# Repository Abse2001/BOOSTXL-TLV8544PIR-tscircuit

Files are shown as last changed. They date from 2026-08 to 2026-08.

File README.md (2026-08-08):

# BOOSTXL-TLV8544PIR tscircuit reconstruction

This is an engineering reconstruction of Texas Instruments' `BOOSTXL-TLV8544PIR` PIR motion-detector BoosterPack.

## Current status

- The complete 70-component, 40-net design is written directly in `index.circuit.tsx`. There is no secondary board file and no project-local component wrapper layer.
- Resistors and capacitors use native tscircuit elements. Every other populated electronic part is instantiated from an exact JLCPCB import: J1-J4, U1-U3, A1, D1-D5, L1/L2, and TP1/TP2.
- TI's two-page schematic was transcribed from SNOU148A Figures 27 and 28 and laid out as two native tscircuit sheets with five native schematic sections. Compact named traces keep every net label at eight characters or fewer and clear of the section dividers. U1 is projected as U1A-U1D op-amp units, the LaunchPad connectors/LEDs sit below the PIR signal chain, and the power/current-monitor circuit occupies sheet 2. C22 is correctly placed across R21, and NT1/NT2/NT3 preserve TI's rail split.
- The unpublished original U3 identity is not guessed. `TLV333IDBVR` is explicitly selected as a qualified, orderable unity-gain-buffer substitute and uses its exact JLCPCB C473369 import with corrected data-sheet pin labels.
- The obsolete SMT PIR is replaced by Murata `IRA-S210ST01` (JLCPCB C152563), using its exact imported three-lead through-hole footprint. The matching lens is Murata `IML-0688`.
- Every populated electrical component has a manufacturer part number and a JLCPCB/LCSC part number. J3/J4 use imported DEALON DZ254S-11-02-48 C5160785 vertical SMT headers, and TP1/TP2 use imported Keystone 5001 C238122.
- The reconstructed board is 60.96 mm × 50.8 mm. Its 43.18-mm header-center spacing (45.72 mm between outer header columns), asymmetric overhang, three holes, and outline are inferred from TI's scale image and BoosterPack grid because TI did not publish native PCB CAD for this board.
- The local v6 router completes 131 PCB traces with 117 vias, 0.30-mm via drills, 0.45-mm via pads, and a bottom GND pour. The circuit JSON contains zero placement, routing, or connectivity errors.
- `bun run release-check` enforces 70 physical components plus the five schematic-only U1/U3 projections, compact schematic labels and divider clearance, net count, routing, zero circuit errors, critical MPNs, supplier coverage, the corrected C22/NT/U3/A1 topology, and a Gerber-mode `tsci check shorts` pass.

## Release status

This is an **orderable prototype release candidate**, not a production-proven clone. The electrical values, topology, MPNs, footprints, and supplier IDs are now traceable. Before paying for assembly, print the 1:1 mechanical overlay and confirm the reconstructed outline/header/hole/lens geometry against the intended LaunchPad. After assembly, execute `docs/bring-up-plan.md`; the IRA-S210 substitution and lens housing require first-article qualification.

- Public source and manufacturing package: <https://github.com/Abse2001/BOOSTXL-TLV8544PIR-tscircuit>
- Published tscircuit package: <https://tscircuit.com/abse/boostxl-tlv8544pir> (`1.0.13`)

The registry build uses the exact OBJ models for J1/J2 and U1 because its per-file upload limit rejects their larger STEP files. The complete STEP models remain in this repository and in the manufacturing exports; electrical and PCB geometry are unchanged.

See:

- `docs/design-verification.md` for value provenance and calculated checkpoints;
- `docs/manufacturing-status.md` for the remaining release gates;
- `docs/mechanical-integration.md` for the board/sensor/lens fit evidence;
- `manufacturing/procurement-status.csv` for exact purchasing selections; and
- `exports/README.md` for generated deliverables.

## Commands

```sh
bun install
bun run release-check
bun run dev
bunx tsci export index.circuit.tsx -f kicad_zip -o exports/BOOSTXL-TLV8544PIR-routed-kicad.zip --disable-parts-engine
```

The build output is written under `dist/`.

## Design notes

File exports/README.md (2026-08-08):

# Generated exports

All files in this directory were regenerated from the same circuit state that passes `bun run release-check`.

| File | Contents |
| --- | --- |
| `BOOSTXL-TLV8544PIR-schematic.svg` | Both TI-style schematic sheets in one stacked review drawing. |
| `BOOSTXL-TLV8544PIR-schematic-page-1.svg` | PIR signal conditioning, LaunchPad connectors, and user LEDs. |
| `BOOSTXL-TLV8544PIR-schematic-page-2.svg` | 3.3-V/5-V filtering, rail splits, current monitor, and U3 buffer. |
| `BOOSTXL-TLV8544PIR-routed-pcb.svg` | Courtyard-visible two-layer routed PCB preview. |
| `BOOSTXL-TLV8544PIR-assembly.svg` | Top assembly drawing with the exact three-lead A1 package. |
| `BOOSTXL-TLV8544PIR-readable-netlist.txt` | Human-readable 70-component/40-net report including selected MPNs. |
| `BOOSTXL-TLV8544PIR-circuit.json` | Complete release-check input/output: 131 PCB traces, 117 vias with 0.30-mm drills and 0.45-mm pads, zero error elements. |
| `BOOSTXL-TLV8544PIR-routed-kicad.zip` | KiCad schematic/PCB/project plus imported models for every non-resistor/non-capacitor electronic component, including J3/J4 and TP1/TP2. |
| `BOOSTXL-TLV8544PIR-gerbers.zip` | Gerber/drill manufacturing data for independent DFM review. |
| `BOOSTXL-TLV8544PIR.step` | Partial board-level STEP model. The standalone merger cannot parse several exact supplier STEP dialects, so use the KiCad ZIP for the separately bundled models. |
| `SHA256SUMS` | SHA-256 checksums for the generated deliverables. |

## Release warning

These files form an orderable **prototype release candidate**, not production-proven hardware. Complete the 1:1 overlay in `docs/mechanical-integration.md`, an independent fabricator-rule DRC/Gerber review, and the first-article tests in `docs/bring-up-plan.md` before a production quantity.

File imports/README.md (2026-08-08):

# JLCPCB / EasyEDA imports

All populated electronic parts other than resistors and capacitors are instantiated directly from components generated with `tsci import --jlcpcb --download --use-exact-footprint`. The exact supplier geometry and downloaded 3D models are retained.

| Designator(s) | Manufacturer part number | JLCPCB/LCSC ID |
| --- | --- | --- |
| U1 | TLV8544PWR | C2867322 |
| U2 | INA226AIDGSR | C49851 |
| U3 | TLV333IDBVR | C473369 |
| D1 | 19-217/R6C-AL1M2VY/3T | C72044 |
| D2 | 19-213/Y2C-CQ2R2L/3T(CY) | C72038 |
| D3 | 19-217/G7C-AN1P2/6T | C2986030 |
| D4, D5 | 1N4148X-TP | C507292 |
| L1, L2 | BLM18HE152SN1D | C82155 |
| J1, J2 | SSQ-110-03-G-D | C3323139 |
| J3, J4 | DZ254S-11-02-48 | C5160785 |
| A1 | IRA-S210ST01 | C152563 |
| TP1, TP2 | Keystone 5001 | C238122 |

The importer sanitized punctuation in several generated TypeScript identifiers and MPN strings. Component identifiers remain valid TypeScript, while the `manufacturerPartNumber` metadata was restored to the supplier's real MPN. The TLV333 import's generated pin aliases were also corrected against the data sheet: pin 2 is `V_NEG` and pin 4 is `IN_NEG`.

H1 is the Murata `IML-0688` Fresnel lens. It is mechanical rather than an electrical source component; its 10.8-mm envelope is shown on board silkscreen and its housing requirements are documented separately.

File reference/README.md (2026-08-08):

# TI reference-data inventory

Collected on 2026-08-07 from official Texas Instruments pages.

## Exact BOOSTXL-TLV8544PIR sources

| Local file | TI document | Contents |
| --- | --- | --- |
| `boostxl-tlv8544pir/BOOSTXL-TLV8544PIR-user-guide-SNOU148A.pdf` | [SNOU148A](https://www.ti.com/lit/pdf/snou148a) | Exact board guide; Figures 27 and 28 are the complete published two-page schematic. |
| `boostxl-tlv8544pir/ultra-low-power-PIR-design-SNAA301.pdf` | [SNAA301](https://www.ti.com/lit/pdf/snaa301) | Application note explaining the low-power PIR analog front end. |
| `rendered-schematics/boostxl-tlv8544pir-schematic-22.png` | SNOU148A page 22 | Verified rendering of schematic page 1. |
| `rendered-schematics/boostxl-tlv8544pir-schematic-23.png` | SNOU148A page 23 | Verified rendering of schematic page 2. |
| `rendered-board/boostxl-tlv8544pir-top-view-04.png` | SNOU148A page 4 | Verified annotated top-view rendering for placement and footprint research. |
| `boostxl-tlv8544pir/component-inventory.csv` | Transcribed from Figures 27-28 | Initial designator/value inventory for reconstruction. |
| `datasheets/TLV8544-datasheet.pdf` | [TLV8544](https://www.ti.com/lit/ds/symlink/tlv8544.pdf) | Quad nanopower op-amp datasheet. |
| `datasheets/INA226-datasheet.pdf` | [INA226](https://www.ti.com/lit/ds/symlink/ina226.pdf) | I2C current/power monitor datasheet. |
| `boosterpack-standard/launchpad-boosterpack-design-guide-SLAA542.pdf` | [SLAA542](https://www.ti.com/lit/pdf/slaa542) | LaunchPad/BoosterPack mechanical and electrical design guidance. |
| `datasheets/IRA-S210ST01-datasheet.pdf` | [Murata IRA-S210ST01](https://www.murata.com/en-global/products/sensor/infrared/products-search/selectionguide) | Selected supported lead-type PIR sensor package and pin data. |
| `datasheets/IML-0688-datasheet.pdf` | [Murata IML-0688](https://www.murata.com/~/media/webrenewal/products/sensor/infrared/lens/iml_spec_0688_en.pdf) | Matching Fresnel-lens dimensions and retention requirements. |

## Additional component evidence

- [Molex 87898-0204 product page](https://www.molex.com/en-us/products/part-detail/0878980204) and [SD-87898-001 drawing](https://www.molex.com/content/dam/molex/molex-dot-com/products/automated/en-us/salesdrawingpdf/878/87898/878980654_sd.pdf): exact J3/J4 series, two circuits, 2.54-mm pitch, and the recommended 1.27 mm × 2.96 mm SMT lands.
- [JLCPCB C3331260](https://jlcpcb.com/partdetail/MOLEX-0878980204/C3331260): exact TI J3/J4 Molex part, listed for pre-order but absent from the current tscircuit/EasyEDA importer.
- [JLCPCB C5160785](https://jlcpcb.com/partdetail/DEALON-DZ254S_11_0248/C5160785): selected stocked J3/J4 replacement; 1×2, 2.54-mm vertical SMT header with 6-mm upright pins.
- [JLCPCB C238122](https://jlcpcb.com/partdetail/Keystone-5001/C238122): exact Keystone 5001 through-hole test point used for TP1/TP2.
- TI's TIDA-01398 BOM identifies the obsolete SMT A1 as `IRS-B210ST01-R1`. A TI engineering response says `IRA-S210ST01` performance should be similar or equal and identifies package as the difference. This supports the project's explicit substitute; it is not treated as an exact BOOSTXL BOM.
- [TI TLV333 data sheet](https://www.ti.com/lit/ds/symlink/tlv333.pdf): operating limits and pinout for the explicit U3 substitute.

TI's current product page does **not** publish native KiCad, Altium, Gerber, pick-and-place, or BOM files for the exact `BOOSTXL-TLV8544PIR`. A public web and GitHub search also found no trustworthy community-native CAD mirror for this exact board. The published electrical source is the schematic embedded in SNOU148A. The exact PCB layout will therefore need to be reconstructed from the schematic, board photographs, and BoosterPack header standard.

## Related TIDA-01398 files

`TIDA-01398` uses the same TLV8544-based low-power PIR concept but is a different wireless reference-design PCB. Do not use its layout, BOM, or CAD files as though they were the BoosterPack.

The directory `tida-01398/` contains TI's public design guide, schematic, BOM, assembly drawing, PCB layer plots, and the original Altium project. The archive was also extracted to `tida-01398/altium-source/`; it contains `.PrjPcb`, `.SchDoc`, and `.PcbDoc` files that recent KiCad versions may import as an Altium project.

## TI downloads requiring login/export approval

These have not been copied into the project because TI gates them behind myTI/export approval:

- [SPRCAG5 - BOOSTXL-TLV8544PIR firmware](https://www.ti.com/tool/download/SPRCAG5)
- [SNOC036 - BOOSTXL-TLV8544PIR Windows GUI](https://www.ti.com/tool/download/SNOC036)
- [TIDCD86 - TIDA-01398 Gerbers](https://www.ti.com/lit/zip/tidcd86)
- [TIDCD87 - TIDA-01398 firmware](https://www.ti.com/tool/download/TIDCD87)

## Original-source gaps and project disposition

- The PIR sensor part number is not printed on the published BoosterPack schematic. The project records the evidence for the obsolete `IRS-B210ST01-R1` and deliberately substitutes exact-import `IRA-S210ST01` plus its matching `IML-0688` lens.
- `U3` is shown electrically but its MPN is not printed. The project deliberately selects and qualifies `TLV333IDBVR`; it does not claim this was TI's original device.
- TI does not publish brands for the passives/LEDs. The project freezes deliberate production selections meeting the printed values and ratings in `manufacturing/procurement-status.csv`.
- SLAA542 defines the connector grid but not this board's expanded outline, three hole positions, chamfers, or lens retention. Those image-derived details still require a 1:1 physical overlay.

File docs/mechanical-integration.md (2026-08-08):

# Mechanical integration

## Reconstructed board datum

The source uses millimetres with the board centered at `(0, 0)`:

- outline: 60.96 mm × 50.8 mm with 2.54-mm corner chamfers;
- J1 center: `(-17.78, 5.08)`;
- J2 center: `(25.40, 5.08)`;
- header-center separation: 43.18 mm; the two-row headers therefore span the standard 45.72-mm outer-column spacing;
- mounting holes: `(-27.94, 22.86)`, `(-27.94, -22.86)`, and `(27.94, -22.86)`, all 3.0-mm diameter; and
- PIR/lens center: `(20.50, -17.00)`.

The outline and placements are scaled from TI's official top view using the known 2.54-mm header grid. The TI BoosterPack standard defines the connector grid, but this particular board visibly extends asymmetrically beyond the basic BoosterPack envelope. Because no exact native board CAD was published, the numbers above are controlled reconstruction dimensions—not metrology of an original unit.

## J3/J4 current jumpers

TI's rendering and Molex's catalog show `87898-0204` as a 1×2, 2.54-mm vertical SMT header fitted with a removable shunt. JLCPCB lists that exact Molex part as C3331260 for pre-order, but it is not available through the current tscircuit/EasyEDA importer. The board therefore uses the stocked, exactly imported DEALON `DZ254S-11-02-48`, JLCPCB C5160785. It preserves the electrical function, pitch, row count, vertical SMT mounting, 6-mm upright pins, and removable-shunt interface.

J3 is placed just inside the left edge with its two upright pins running left-to-right, matching TI's top view; J4 uses the same vertical header rotated 90 degrees near the top edge. Fit 2.54-mm shunts such as JLCPCB C5305 for normal operation. Remove a shunt only when inserting an ammeter across that header. Confirm header and shunt clearance on the 1:1 overlay.

## A1 sensor

Murata `IRA-S210ST01` is a lead-type dual-element PIR sensor. Its manufacturer drawing specifies a 9.2-mm-diameter, 4.7-mm-high can, 0.45-mm leads, and drain/source/ground functions. The exact JLCPCB C152563 import supplies three 0.9144-mm drilled plated holes on its nonrectangular lead pattern and the manufacturer-scale courtyard/model.

This package change is deliberate: TI support reported that the obsolete `IRS-B210ST01-R1` and `IRA-S210ST01` should have similar or equal performance, with package being the difference. Sensitivity still requires first-article qualification.

## H1 lens and housing

Murata `IML-0688` is specified for `IRA-S210ST01`. Its drawing gives:

- 10.8 mm × 10.8 mm maximum plan envelope;
- 10.3-mm nominal circular base;
- 8.55-mm overall height; and
- keyed tabs that must align with the sensor/lens orientation.

Murata also states that the lens and sensor should be press-fit and that the equipment must include housing or other retention to prevent lens dislocation. The PCB silkscreen shows the 10.8-mm envelope for inspection, but silkscreen is not retention. The enclosure must locate the lens axially, preserve the tab orientation, avoid touching the sensor can, and exclude direct drafts/sunlight from the optical path.

## Mandatory 1:1 check

Before fabrication, export the PCB SVG/PDF at 100% scale and verify with calipers:

1. both header rows mate without force;
2. the three mounting holes align and do not clash with the LaunchPad;
3. the asymmetric outline clears USB connectors, jumpers, antennas, and enclosure walls;
4. J3/J4 bodies and removable shunts match the required access direction without colliding with nearby parts;
5. the A1 body and leads fit the exact holes; and
6. the IML-0688/housing stack centers over A1 without covering solderable parts or colliding with MH3.

Record the measured deviations in the hardware revision notes before ordering more than the first-article quantity.

Sources:

- `reference/boosterpack-standard/launchpad-boosterpack-design-guide-SLAA542.pdf`
- `reference/boostxl-tlv8544pir/BOOSTXL-TLV8544PIR-user-guide-SNOU148A.pdf`
- `reference/datasheets/IRA-S210ST01-datasheet.pdf`
- `reference/datasheets/IML-0688-datasheet.pdf`
- [Murata PIR selection guide](https://www.murata.com/en-global/products/sensor/infrared/products-search/selectionguide)
- [TI E2E obsolete-sensor response](https://e2e.ti.com/support/tools/simulation-hardware-system-design-tools-group/sim-hw-system-design/f/simulation-hardware-system-design-tools-forum/932724/tida-01398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)

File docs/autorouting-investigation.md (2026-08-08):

# Autorouting investigation

The checked-in design pins tscircuit's local capacity autorouter to `v6`, uses `2x` effort, a 0.20-mm nominal trace width, 0.15-mm trace clearance, 0.30-mm minimum via drills, and 0.45-mm minimum via pads. A fresh route of the direct `index.circuit.tsx` implementation with exact JLCPCB imports completes 131 PCB traces with 117 vias and zero generated circuit-JSON error elements.

Two lower-via experiments were rejected on 2026-08-07:

- A dedicated GND `fanout` phase targeting the bottom copper plane reached a tscircuit follow-up-stage error (`Autorouting follow-up stage is missing the preceding stage output`).
- Whole-board `fanout` rejected intentionally single-ended LaunchPad nets such as `I2C_CS` because they have no second on-board target.

An uncached `v1` router run also failed to converge within the bounded benchmark window. With the larger manufacturing-safe via constraints, the retained `v6` route completes in roughly eight minutes on the same workstation. No failed experiment is retained in the source or generated exports.

The 117-via route is reproducible and useful for connectivity review, but it still needs an independent human/fabricator-rule review before production. That review should share local GND returns where practical, reduce unnecessary layer changes, preserve a continuous return plane, and give special attention to the high-impedance PIR input and the R21/U3/INA226 measurement loop.

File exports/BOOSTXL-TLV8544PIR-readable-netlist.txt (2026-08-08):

COMPONENTS:
 - J1: SSQ-110-03-G-D
 - J2: SSQ-110-03-G-D
 - C1: 0.01uF 0603 capacitor
 - C2: 0.01uF 0603 capacitor
 - C3: 0.01uF 0603 capacitor
 - C4: 0.01uF 0603 capacitor
 - A1: IRA-S210ST01
 - R12: 619kΩ res0603 resistor
 - C10: 100uF 1206 capacitor
 - C11: 10uF 0603 capacitor
 - C12: 1uF 0603 capacitor
 - C13: 0.1uF 0603 capacitor
 - C14: 0.01uF 0603 capacitor
 - C15: 1000pF 0603 capacitor
 - C16: 100pF 0603 capacitor
 - U1: TLV8544PWR
 - U1A:
 - U1B:
 - U1C:
 - U1D:
 - R14: 0Ω res0603 resistor
 - R16: 1.3MΩ res0603 resistor
 - R6: 6.81kΩ res0603 resistor
 - C5: 33uF 0805 capacitor
 - R9: 1.5MΩ res0603 resistor
 - C6: 0.01uF 0603 capacitor
 - D4: D4, source_component
 - D5: D5, source_component
 - R4: 10kΩ res0603 resistor
 - C9: 3.3uF 0805 capacitor
 - R13: 68.1kΩ res0603 resistor
 - R7: 15MΩ res0805 resistor
 - C7: 1000pF 0603 capacitor
 - R17: 0Ω res0603 resistor
 - C17: 0.1uF 0603 capacitor
 - R15: 0Ω res0603 resistor
 - R5: 10kΩ res0603 resistor
 - R8: 15MΩ res0805 resistor
 - R11: 15MΩ res0805 resistor
 - R18: 15MΩ res0805 resistor
 - R20: 15MΩ res0805 resistor
 - C8: 0.1uF 0603 capacitor
 - C18: 0.1uF 0603 capacitor
 - R10: 10kΩ res0603 resistor
 - R19: 10kΩ res0603 resistor
 - C19: 0.1uF 0603 capacitor
 - C20: 10uF 0603 capacitor
 - R1: 442Ω res0805 resistor
 - D1: D1, source_component
 - R2: 487Ω res0805 resistor
 - D2: D2, source_component
 - R3: 487Ω res0805 resistor
 - D3: D3, source_component
 - TP1: 5001
 - L1: BLM18HE152SN1D
 - C24: 0.1uF 0603 capacitor
 - C25: 10uF 0603 capacitor
 - L2: BLM18HE152SN1D
 - C26: 0.1uF 0603 capacitor
 - C27: 0.1uF 0603 capacitor
 - C28: 10uF 0603 capacitor
 - C29: 0.1uF 0603 capacitor
 - NT1: 0Ω res0603 resistor
 - NT2: 0Ω res0603 resistor
 - NT3: 0Ω res0603 resistor
 - J3: DZ254S-11-02-48
 - J4: DZ254S-11-02-48
 - R21: 15kΩ res0603 resistor
 - C22: 0.1uF 0603 capacitor
 - U3: TLV333IDBVR
 - U3A:
 - C23: 0.1uF 0603 capacitor
 - U2: INA226AIDGSR
 - C21: 0.1uF 0603 capacitor
 - TP2: 5001

NET: PIR_IN
  - C16 pin1 (+)
  - C15 pin1 (+)
  - C14 pin1 (+)
  - C13 pin1 (+)
  - C12 pin1 (+)
  - C11 pin1 (+)
  - C10 pin1 (+)
  - R12 pin2
  - A1 d

NET: PIR_RAW
  - R14 pin1
  - A1 s

NET: PIR_VO
  - R16 pin1
  - R14 pin2
  - U1 IN_A_POS

NET: AC_RET
  - C5 pin1 (+)
  - R6 pin2

NET: A_INV
  - D5 cathode (-)
  - D4 anode (+)
  - C6 pin2 (-)
  - R9 pin2
  - R6 pin1
  - U1 IN_A_NEG

NET: STG1_OUT
  - R4 pin2
  - C2 pin1 (+)
  - J1 pin3

NET: A_OUT
  - C9 pin1 (+)
  - R4 pin1
  - D5 anode (+)
  - D4 cathode (-)
  - C6 pin1 (+)
  - R9 pin1
  - U1 OUT_A

NET: INTER
  - R13 pin1
  - C9 pin2 (-)

NET: B_INV
  - C7 pin2 (-)
  - R7 pin2
  - R13 pin2
  - U1 IN_B_NEG

NET: B_REF
  - C17 pin1 (+)
  - R17 pin1
  - U1 IN_B_POS

NET: B_OUT
  - R15 pin1
  - C7 pin1 (+)
  - R7 pin1
  - U1 OUT_B

NET: PIR_BUS
  - R5 pin1
  - R15 pin2
  - U1 IN_D_NEG
  - U1 IN_C_POS

NET: PIR_SGL
  - R5 pin2
  - C4 pin1 (+)
  - J1 pin11

NET: REF_MID
  - R18 pin1
  - R11 pin2
  - R17 pin2

NET: REF_HI
  - C8 pin1 (+)
  - R11 pin1
  - R8 pin2
  - U1 IN_C_NEG

NET: REF_LO
  - C18 pin1 (+)
  - R20 pin1
  - R18 pin2
  - U1 IN_D_POS

NET: C_OUT
  - R10 pin1
  - U1 OUT_C

NET: PIR_HI
  - R10 pin2
  - C1 pin1 (+)
  - J1 pin10

NET: D_OUT
  - R19 pin1
  - U1 OUT_D

NET: PIR_LO
  - R19 pin2
  - C3 pin1 (+)
  - J1 pin12

NET: RLED
  - R1 pin1
  - J1 pin18

NET: D1_ANODE
  - D1 anode (+)
  - R1 pin2

NET: YLED
  - R2 pin1
  - J1 pin20

NET: D2_ANODE
  - D2 anode (+)
  - R2 pin2

NET: OLED
  - R3 pin1
  - J1 pin16

NET: D3_ANODE
  - D3 anode (+)
  - R3 pin2

NET: V33_LPD
  - L1 pin1
  - J1 pin1

NET: V5_LPD
  - L2 pin1
  - J1 pin2

NET: V33_REF
  - NT2 pin2
  - R8 pin1

NET: V_PIR
  - J3 pin1
  - R12 pin1

NET: V33_FILT
  - J4 pin2
  - J3 pin2
  - NT1 pin1
  - C25 pin1 (+)
  - C24 pin1 (+)
  - L1 pin2

NET: V_TLV
  - U3 IN_POS
  - C22 pin2 (-)
  - R21 pin2
  - J4 pin1
  - C20 pin1 (+)
  - C19 pin1 (+)
  - U1 V_POS

NET: V5_FILT
  - C23 pin1 (+)
  - U3 V_POS
  - C29 pin1 (+)
  - C28 pin1 (+)
  - C27 pin1 (+)
  - C26 pin1 (+)
  - L2 pin2

NET: I2C_SDA
  - U2 SDA
  - J1 pin19

NET: I2C_SCL
  - U2 SCL
  - J1 pin17

NET: BUF_OUT
  - U3 IN_NEG
  - U3 OUT
  - U2 VIN_NEG

NET: V33_TLV
  - U2 VIN_POS
  - U2 VBUS
  - C22 pin1 (+)
  - R21 pin1
  - NT3 pin1
  - NT2 pin1
  - NT1 pin2

NET: V33_INA
  - C21 pin1 (+)
  - U2 VS_POS
  - NT3 pin2

NET: GND
  - TP2 pin1
  - C21 pin2 (-)
  - U2 GND
  - U2 A0
  - U2 A1
  - C23 pin2 (-)
  - U3 V_NEG
  - C29 pin2 (-)
  - C28 pin2 (-)
  - C27 pin2 (-)
  - C26 pin2 (-)
  - C25 pin2 (-)
  - C24 pin2 (-)
  - TP1 pin1
  - D3 cathode (-)
  - D2 cathode (-)
  - D1 cathode (-)
  - C20 pin2 (-)
  - C19 pin2 (-)
  - C18 pin2 (-)
  - C8 pin2 (-)
  - R20 pin2
  - C17 pin2 (-)
  - C5 pin2 (-)
  - R16 pin2
  - U1 V_NEG
  - C16 pin2 (-)
  - C15 pin2 (-)
  - C14 pin2 (-)
  - C13 pin2 (-)
  - C12 pin2 (-)
  - C11 pin2 (-)
  - C10 pin2 (-)
  - A1 g
  - C4 pin2 (-)
  - C3 pin2 (-)
  - C2 pin2 (-)
  - C1 pin2 (-)
  - J2 pin20
  - J1 pin4

EMPTY NET PINS:
  - J1 pin14

COMPONENT_PINS:
J1 (SSQ-110-03-G-D)
- pin1: NETS(V33_LPD)
- pin2: NETS(V5_LPD)
- pin3: NETS(STG1_OUT)
- pin4: NETS(GND)
- pin5: NOT_CONNECTED
- pin6: NOT_CONNECTED
- pin7: NOT_CONNECTED
- pin8: NOT_CONNECTED
- pin9: NOT_CONNECTED
- pin10: NETS(PIR_HI)
- pin11: NETS(PIR_SGL)
- pin12: NETS(PIR_LO)
- pin13: NOT_CONNECTED
- pin14: NETS(I2C_CS)
- pin15: NOT_CONNECTED
- pin16: NETS(OLED)
- pin17: NETS(I2C_SCL)
- pin18: NETS(RLED)
- pin19: NETS(I2C_SDA)
- pin20: NETS(YLED)

J2 (SSQ-110-03-G-D)
- pin1: NOT_CONNECTED
- pin2: NOT_CONNECTED
- pin3: NOT_CONNECTED
- pin4: NOT_CONNECTED
- pin5: NOT_CONNECTED
- pin6: NOT_CONNECTED
- pin7: NOT_CONNECTED
- pin8: NOT_CONNECTED
- pin9: NOT_CONNECTED
- pin10: NOT_CONNECTED
- pin11: NOT_CONNECTED
- pin12: NOT_CONNECTED
- pin13: NOT_CONNECTED
- pin14: NOT_CONNECTED
- pin15: NOT_CONNECTED
- pin16: NOT_CONNECTED
- pin17: NOT_CONNECTED
- pin18: NOT_CONNECTED
- pin19: NOT_CONNECTED
- pin20: NETS(GND)

C1 (0.01uF 0603)
- pin1(anode, pos, left): NETS(PIR_HI)
- pin2(cathode, neg, right): NETS(GND)

C2 (0.01uF 0603)
- pin1(anode, pos, left): NETS(STG1_OUT)
- pin2(cathode, neg, right): NETS(GND)

C3 (0.01uF 0603)
- pin1(anode, pos, left): NETS(PIR_LO)
- pin2(cathode, neg, right): NETS(GND)

C4 (0.01uF 0603)
- pin1(anode, pos, left): NETS(PIR_SGL)
- pin2(cathode, neg, right): NETS(GND)

A1 (IRA-S210ST01)
- pin1(d): NETS(PIR_IN)
- pin2(s): NETS(PIR_RAW)
- pin3(g): NETS(GND)

R12 (619kΩ res0603)
- pin1(anode, pos, left): NETS(V_PIR)
- pin2(cathode, neg, right): NETS(PIR_IN)

C10 (100uF 1206)
- pin1(anode, pos, left): NETS(PIR_IN)
- pin2(cathode, neg, right): NETS(GND)

C11 (10uF 0603)
- pin1(anode, pos, left): NETS(PIR_IN)
- pin2(cathode, neg, right): NETS(GND)

C12 (1uF 0603)
- pin1(anode, pos, left): NETS(PIR_IN)
- pin2(cathode, neg, right): NETS(GND)

C13 (0.1uF 0603)
- pin1(anode, pos, left): NETS(PIR_IN)
- pin2(cathode, neg, right): NETS(GND)

C14 (0.01uF 0603)
- pin1(anode, pos, left): NETS(PIR_IN)
- pin2(cathode, neg, right): NETS(GND)

C15 (1000pF 0603)
- pin1(anode, pos, left): NETS(PIR_IN)
- pin2(cathode, neg, right): NETS(GND)

C16 (100pF 0603)
- pin1(anode, pos, left): NETS(PIR_IN)
- pin2(cathode, neg, right): NETS(GND)

U1 (TLV8544PWR)
- pin1(OUT_A): NETS(A_OUT)
- pin2(IN_A_NEG): NETS(A_INV)
- pin3(IN_A_POS): NETS(PIR_VO)
- pin4(V_POS): NETS(V_TLV)
- pin5(IN_B_POS): NETS(B_REF)
- pin6(IN_B_NEG): NETS(B_INV)
- pin7(OUT_B): NETS(B_OUT)
- pin8(OUT_C): NETS(C_OUT)
- pin9(IN_C_NEG): NETS(REF_HI)
- pin10(IN_C_POS): NETS(PIR_BUS)
- pin11(V_NEG): NETS(GND)
- pin12(IN_D_POS): NETS(REF_LO)
- pin13(IN_D_NEG): NETS(PIR_BUS)
- pin14(OUT_D): NETS(D_OUT)

U1A

U1B

U1C

U1D

R14 (0Ω res0603)
- pin1(anode, pos, left): NETS(PIR_RAW)
- pin2(cathode, neg, right): NETS(PIR_VO)

R16 (1.3MΩ res0603)
- pin1(anode, pos, left): NETS(PIR_VO)
- pin2(cathode, neg, right): NETS(GND)

R6 (6.81kΩ res0603)
- pin1(anode, pos, left): NETS(A_INV)
- pin2(cathode, neg, right): NETS(AC_RET)

C5 (33uF 0805)
- pin1(anode, pos, left): NETS(AC_RET)
- pin2(cathode, neg, right): NETS(GND)

R9 (1.5MΩ res0603)
- pin1(anode, pos, left): NETS(A_OUT)
- pin2(cathode, neg, right): NETS(A_INV)

C6 (0.01uF 0603)
- pin1(pos, anode, left): NETS(A_OUT)
- pin2(neg, cathode, right): NETS(A_INV)

D4 (1N4148X-TP)
- pin1(cathode, neg): NETS(A_OUT)
- pin2(anode, pos): NETS(A_INV)

D5 (1N4148X-TP)
- pin1(cathode, neg): NETS(A_INV)
- pin2(anode, pos): NETS(A_OUT)

R4 (10kΩ res0603)
- pin1(anode, pos, left): NETS(A_OUT)
- pin2(cathode, neg, right): NETS(STG1_OUT)

C9 (3.3uF 0805)
- pin1(pos, anode, left): NETS(A_OUT)
- pin2(neg, cathode, right): NETS(INTER)

R13 (68.1kΩ res0603)
- pin1(anode, pos, left): NETS(INTER)
- pin2(cathode, neg, right): NETS(B_INV)

R7 (15MΩ res0805)
- pin1(anode, pos, left): NETS(B_OUT)
- pin2(cathode, neg, right): NETS(B_INV)

C7 (1000pF 0603)
- pin1(pos, anode, left): NETS(B_OUT)
- pin2(neg, cathode, right): NETS(B_INV)

R17 (0Ω res0603)
- pin1(anode, pos, left): NETS(B_REF)
- pin2(cathode, neg, right): NETS(REF_MID)

C17 (0.1uF 0603)
- pin1(anode, pos, left): NETS(B_REF)
- pin2(cathode, neg, right): NETS(GND)

R15 (0Ω res0603)
- pin1(anode, pos, left): NETS(B_OUT)
- pin2(cathode, neg, right): NETS(PIR_BUS)

R5 (10kΩ res0603)
- pin1(anode, pos, left): NETS(PIR_BUS)
- pin2(cathode, neg, right): NETS(PIR_SGL)

R8 (15MΩ res0805)
- pin1(anode, pos, left): NETS(V33_REF)
- pin2(cathode, neg, right): NETS(REF_HI)

R11 (15MΩ res0805)
- pin1(anode, pos, left): NETS(REF_HI)
- pin2(cathode, neg, right): NETS(REF_MID)

R18 (15MΩ res0805)
- pin1(anode, pos, left): NETS(REF_MID)
- pin2(cathode, neg, right): NETS(REF_LO)

R20 (15MΩ res0805)
- pin1(anode, pos, left): NETS(REF_LO)
- pin2(cathode, neg, right): NETS(GND)

C8 (0.1uF 0603)
- pin1(anode, pos, left): NETS(REF_HI)
- pin2(cathode, neg, right): NETS(GND)

C18 (0.1uF 0603)
- pin1(anode, pos, left): NETS(REF_LO)
- pin2(cathode, neg, right): NETS(GND)

R10 (10kΩ res0603)
- pin1(anode, pos, left): NETS(C_OUT)
- pin2(cathode, neg, right): NETS(PIR_HI)

R19 (10kΩ res0603)
- pin1(anode, pos, left): NETS(D_OUT)
- pin2(cathode, neg, right): NETS(PIR_LO)

C19 (0.1uF 0603)
- pin1(anode, pos, left): NETS(V_TLV)
- pin2(cathode, neg, right): NETS(GND)

C20 (10uF 0603)
- pin1(anode, pos, left): NETS(V_TLV)
- pin2(cathode, neg, right): NETS(GND)

R1 (442Ω res0805)
- pin1(anode, pos, left): NETS(RLED)
- pin2(cathode, neg, right): NETS(D1_ANODE)

D1 (19-217/R6C-AL1M2VY/3T)
- pin1(cathode, neg): NETS(GND)
- pin2(anode, pos): NETS(D1_ANODE)

R2 (487Ω res0805)
- pin1(anode, pos, left): NETS(YLED)
- pin2(cathode, neg, right): NETS(D2_ANODE)

D2 (19-213/Y2C-CQ2R2L/3T(CY))
- pin1(cathode, neg): NETS(GND)
- pin2(anode, pos): NETS(D2_ANODE)

R3 (487Ω res0805)
- pin1(anode, pos, left): NETS(OLED)
- pin2(cathode, neg, right): NETS(D3_ANODE)

D3 (19-217/G7C-AN1P2/6T)
- pin1(anode, pos): NETS(D3_ANODE)
- pin2(cathode, neg): NETS(GND)

TP1 (5001)
- pin1: NETS(GND)

L1 (BLM18HE152SN1D)
- pin1: NETS(V33_LPD)
- pin2: NETS(V33_FILT)

C24 (0.1uF 0603)
- pin1(anode, pos, left): NETS(V33_FILT)
- pin2(cathode, neg, right): NETS(GND)

C25 (10uF 0603)
- pin1(anode, pos, left): NETS(V33_FILT)
- pin2(cathode, neg, right): NETS(GND)

L2 (BLM18HE152SN1D)
- pin1: NETS(V5_LPD)
- pin2: NETS(V5_FILT)

C26 (0.1uF 0603)
- pin1(anode, pos, left): NETS(V5_FILT)
- pin2(cathode, neg, right): NETS(GND)

C27 (0.1uF 0603)
- pin1(anode, pos, left): NETS(V5_FILT)
- pin2(cathode, neg, right): NETS(GND)

C28 (10uF 0603)
- pin1(anode, pos, left): NETS(V5_FILT)
- pin2(cathode, neg, right): NETS(GND)

C29 (0.1uF 0603)
- pin1(anode, pos, left): NETS(V5_FILT)
- pin2(cathode, neg, right): NETS(GND)

NT1 (0Ω res0603)
- pin1(anode, pos, left): NETS(V33_FILT)
- pin2(cathode, neg, right): NETS(V33_TLV)

NT2 (0Ω res0603)
- pin1(anode, pos, left): NETS(V33_TLV)
- pin2(cathode, neg, right): NETS(V33_REF)

NT3 (0Ω res0603)
- pin1(anode, pos, left): NETS(V33_TLV)
- pin2(cathode, neg, right): NETS(V33_INA)

J3 (DZ254S-11-02-48)
- pin1: NETS(V_PIR)
- pin2: NETS(V33_FILT)

J4 (DZ254S-11-02-48)
- pin1: NETS(V_TLV)
- pin2: NETS(V33_FILT)

R21 (15kΩ res0603)
- pin1(anode, pos, left): NETS(V33_TLV)
- pin2(cathode, neg, right): NETS(V_TLV)

C22 (0.1uF 0603)
- pin1(anode, pos, left): NETS(V33_TLV)
- pin2(cathode, neg, right): NETS(V_TLV)

U3 (TLV333IDBVR)
- pin1(OUT): NETS(BUF_OUT)
- pin2(V_NEG): NETS(GND)
- pin3(IN_POS): NETS(V_TLV)
- pin4(IN_NEG): NETS(BUF_OUT)
- pin5(V_POS): NETS(V5_FILT)

U3A

C23 (0.1uF 0603)
- pin1(anode, pos, left): NETS(V5_FILT)
- pin2(cathode, neg, right): NETS(GND)

U2 (INA226AIDGSR)
- pin1(A1): NETS(GND)
- pin2(A0): NETS(GND)
- pin3(Alert): NOT_CONNECTED
- pin4(SDA): NETS(I2C_SDA)
- pin5(SCL): NETS(I2C_SCL)
- pin6(VS_POS): NETS(V33_INA)
- pin7(GND): NETS(GND)
- pin8(VBUS): NETS(V33_TLV)
- pin9(VIN_NEG): NETS(BUF_OUT)
- pin10(VIN_POS): NETS(V33_TLV)

C21 (0.1uF 0603)
- pin1(anode, pos, left): NETS(V33_INA)
- pin2(cathode, neg, right): NETS(GND)

TP2 (5001)
- pin1: NETS(GND)

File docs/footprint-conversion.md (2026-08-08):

# Footprint and import decisions

The current project rule is simple: resistors and capacitors may use native tscircuit elements; every other populated electronic component must be instantiated from an exact JLCPCB import.

Earlier footprinter comparisons remain useful geometry evidence, but they no longer cause a non-passive part to be converted to a native element.

| Designator(s) | JLCPCB source | Recorded best package-correct IoU | Current decision |
| --- | --- | ---: | --- |
| U1 | C2867322 / TLV8544PWR | 1.0000 | Exact JLCPCB import. |
| U2 | C49851 / INA226AIDGSR | 0.9623 | Exact JLCPCB import. |
| U3 | C473369 / TLV333IDBVR | 0.959821 | Exact JLCPCB import with corrected pin aliases. |
| D4, D5 | C507292 / 1N4148X-TP | 1.0000 | Exact JLCPCB import. |
| L1, L2 | C82155 / BLM18HE152SN1D | 1.0000 | Exact JLCPCB import. |
| J1, J2 | C3323139 / SSQ-110-03-G-D | 0.1484 | Exact JLCPCB import. |
| A1 | C152563 / IRA-S210ST01 | 0.1387 copper; 0.0131 holes | Exact JLCPCB import. |
| D1-D3 | C72044, C72038, C2986030 | Not required | Exact JLCPCB imports. |
| J3, J4 | C5160785 / DZ254S-11-02-48 | Not required | Exact vertical SMT JLCPCB import; upright pins match TI's top view. |
| TP1, TP2 | C238122 / Keystone 5001 | Not required | Exact through-hole JLCPCB import. |

The release verifier rejects native `<chip>`, `<diode>`, `<led>`, `<pinheader>`, `<testpoint>`, or `<inductor>` instantiations in `index.circuit.tsx` so this policy cannot silently regress.

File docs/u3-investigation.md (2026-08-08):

# U3 investigation and substitute qualification

## What TI publishes

SNOU148A Figure 28 defines U3 electrically but does not identify its manufacturer part number. The schematic and official board image establish a single op-amp in the standard SOT-23-5 pinout:

- pin 1 `OUT`, pin 2 `V-`, pin 3 `IN+`, pin 4 `IN-`, pin 5 `V+`;
- `OUT` tied to `IN-` as a unity-gain follower;
- 5-V supply and ground;
- `IN+` sensing `V+_TLV`; and
- `OUT` buffering the low side of R21 into INA226 `VIN-` while INA226 `VIN+` senses `3.3VTLV`.

TI's published material does not provide enough evidence to claim the exact original U3 identity.

## Selected production substitute

The reconstruction explicitly selects Texas Instruments `TLV333IDBVR`, JLCPCB/LCSC C473369. This is a substitute selection, not a claim about the original BOM.

The TI data sheet qualifies it for this follower:

- 1.8-V to 5.5-V operation, so a 5-V supply is valid;
- unity-gain stable;
- rail-to-rail input/output and common-mode range 0.1 V beyond both rails, covering the approximately 3.3-V sense node;
- standard DBV SOT-23-5 pinout matching Figure 28;
- 15-µV maximum input offset at 25 °C; and
- input bias current in the picoamp range.

At R21 = 15.0 kΩ, 15 µV corresponds to 1 nA of worst-case 25 °C input-referred current error. The INA226 shunt-voltage LSB of 2.5 µV corresponds to 0.167 nA through R21, so U3 offset is measurable but small relative to the board's microamp-scale current measurement.

## Footprint decision

`tsci import C473369 --jlcpcb --download --use-exact-footprint` supplies exact model provenance. The package-correct footprinter comparison produced 95.9821% copper IoU for:

`sot25_w2.2157mm_pl1.0276mm_pin1location(leftside,bottom)`

That comparison remains useful evidence, but the project's current sourcing rule requires non-passives to be instantiated from JLCPCB imports. `index.circuit.tsx` therefore uses the exact C473369 import. The generated import's incorrect pin aliases were corrected against the TI data sheet: pin 2 is `V_NEG` and pin 4 is `IN_NEG`.

## Remaining validation

The substitute is electrically and geometrically qualified on paper. First-article bring-up must still compare the INA226 reading with a calibrated series ammeter at room temperature and across the expected operating range. That test validates the complete signal chain, soldering, and actual offset rather than only the data-sheet limits.

Sources:

- [TI BOOSTXL-TLV8544PIR user guide](https://www.ti.com/lit/ug/snou148a/snou148a.pdf)
- [TI TLV333 data sheet](https://www.ti.com/lit/ds/symlink/tlv333.pdf)
- [JLCPCB TLV333IDBVR C473369](https://jlcpcb.com/partdetail/TexasInstruments-TLV333IDBVR/C473369)

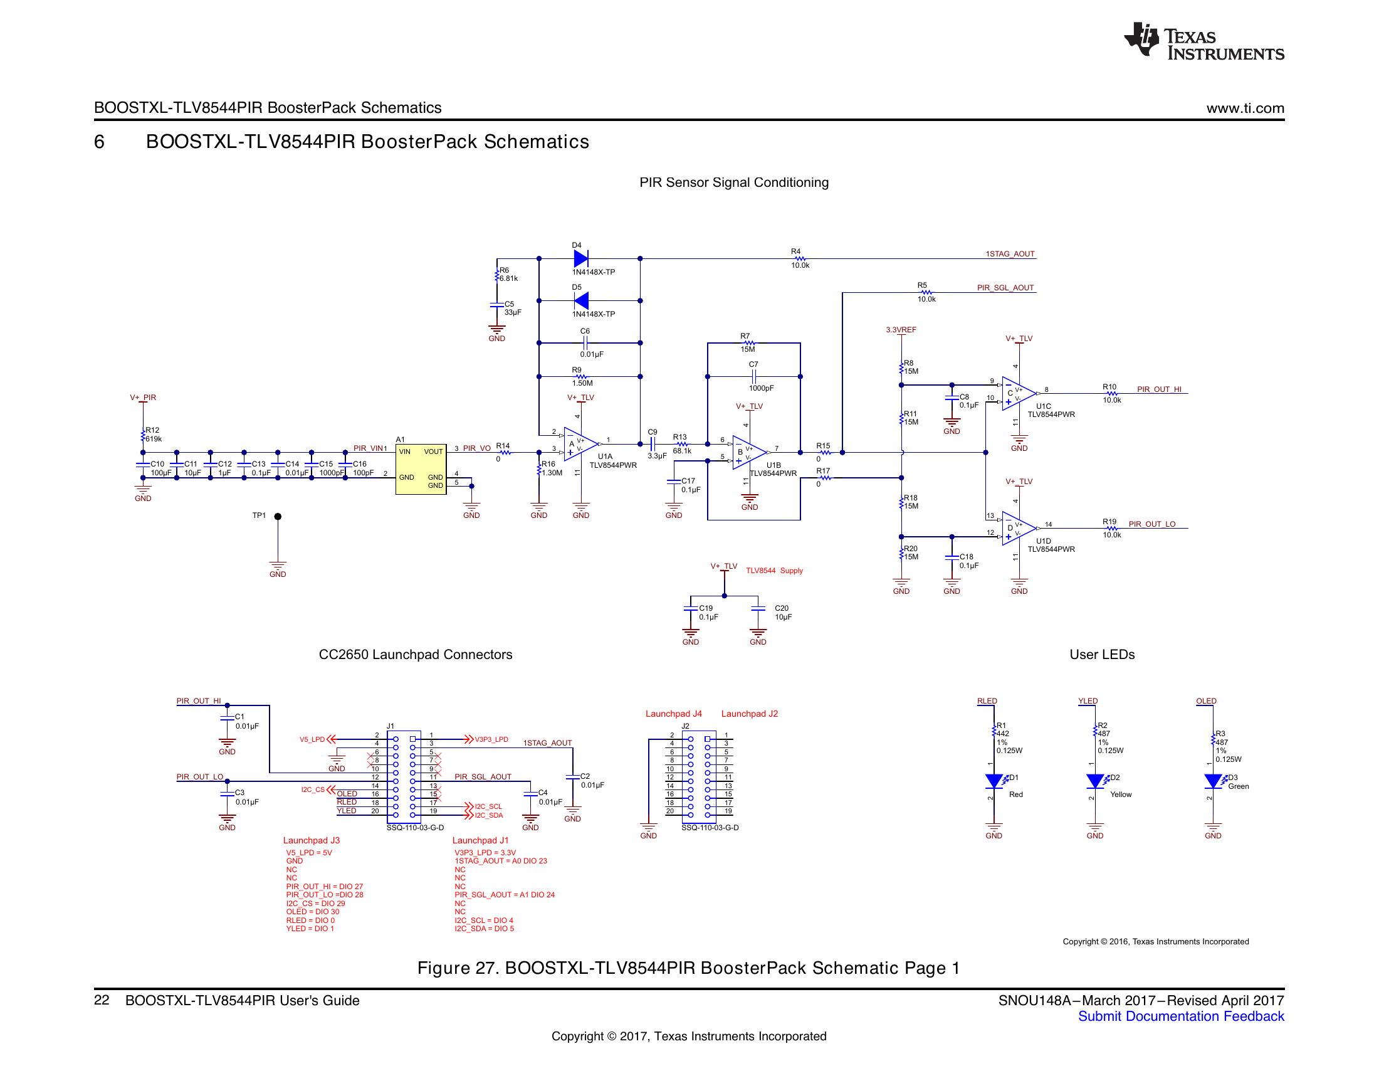
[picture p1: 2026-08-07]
reference/rendered-schematics/boostxl-tlv8544pir-schematic-22.png

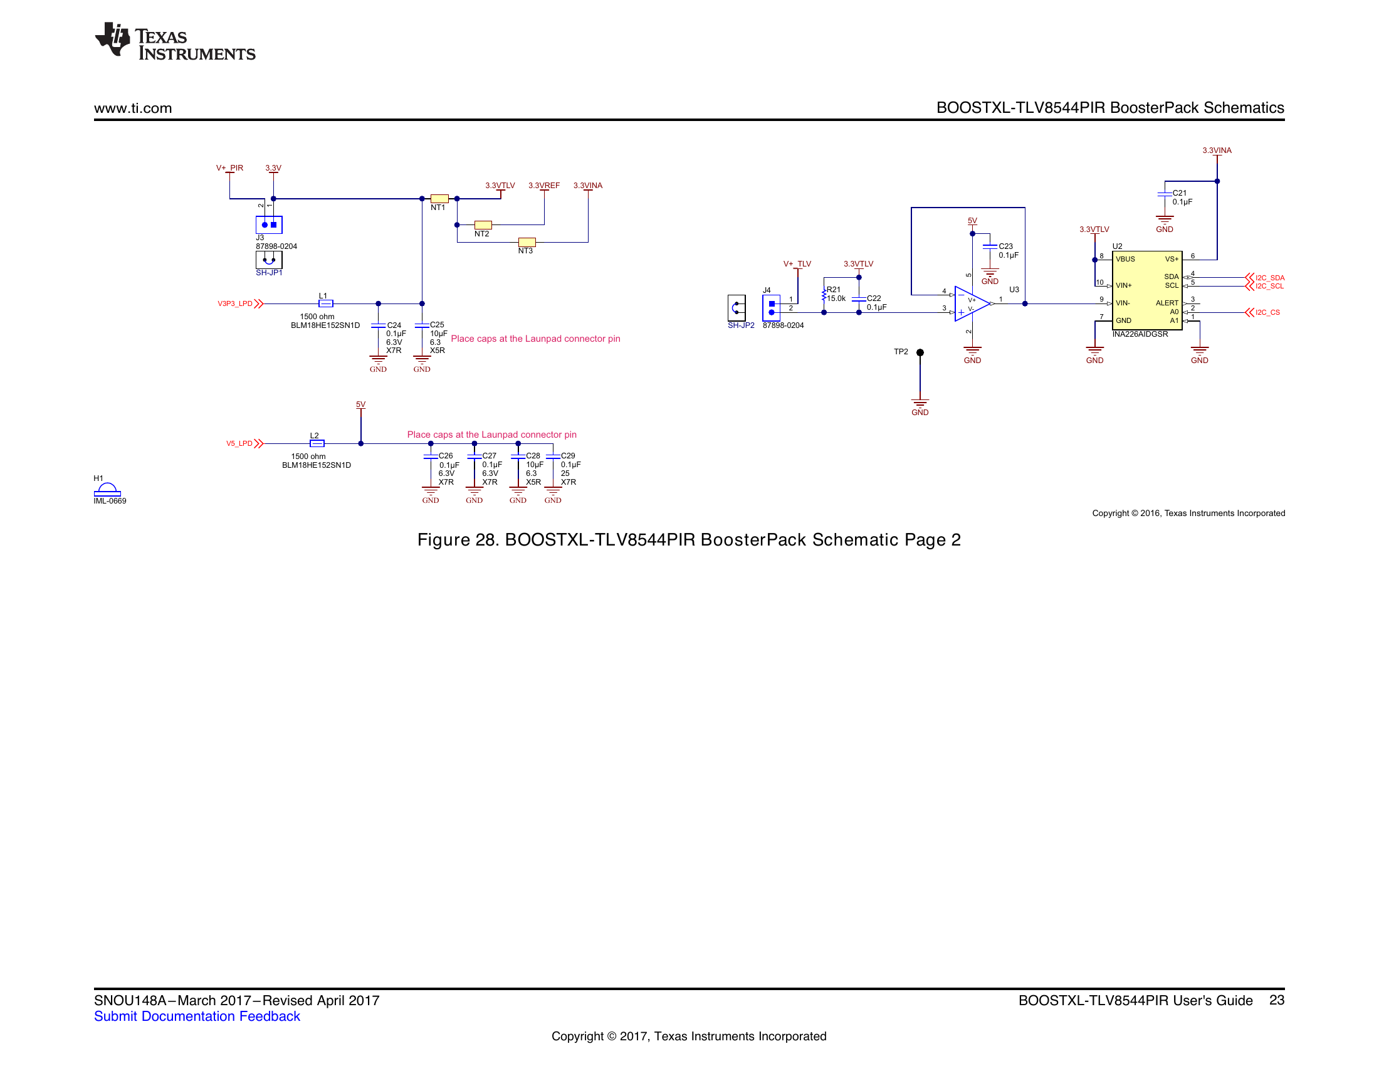
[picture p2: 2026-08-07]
reference/rendered-schematics/boostxl-tlv8544pir-schematic-23.png

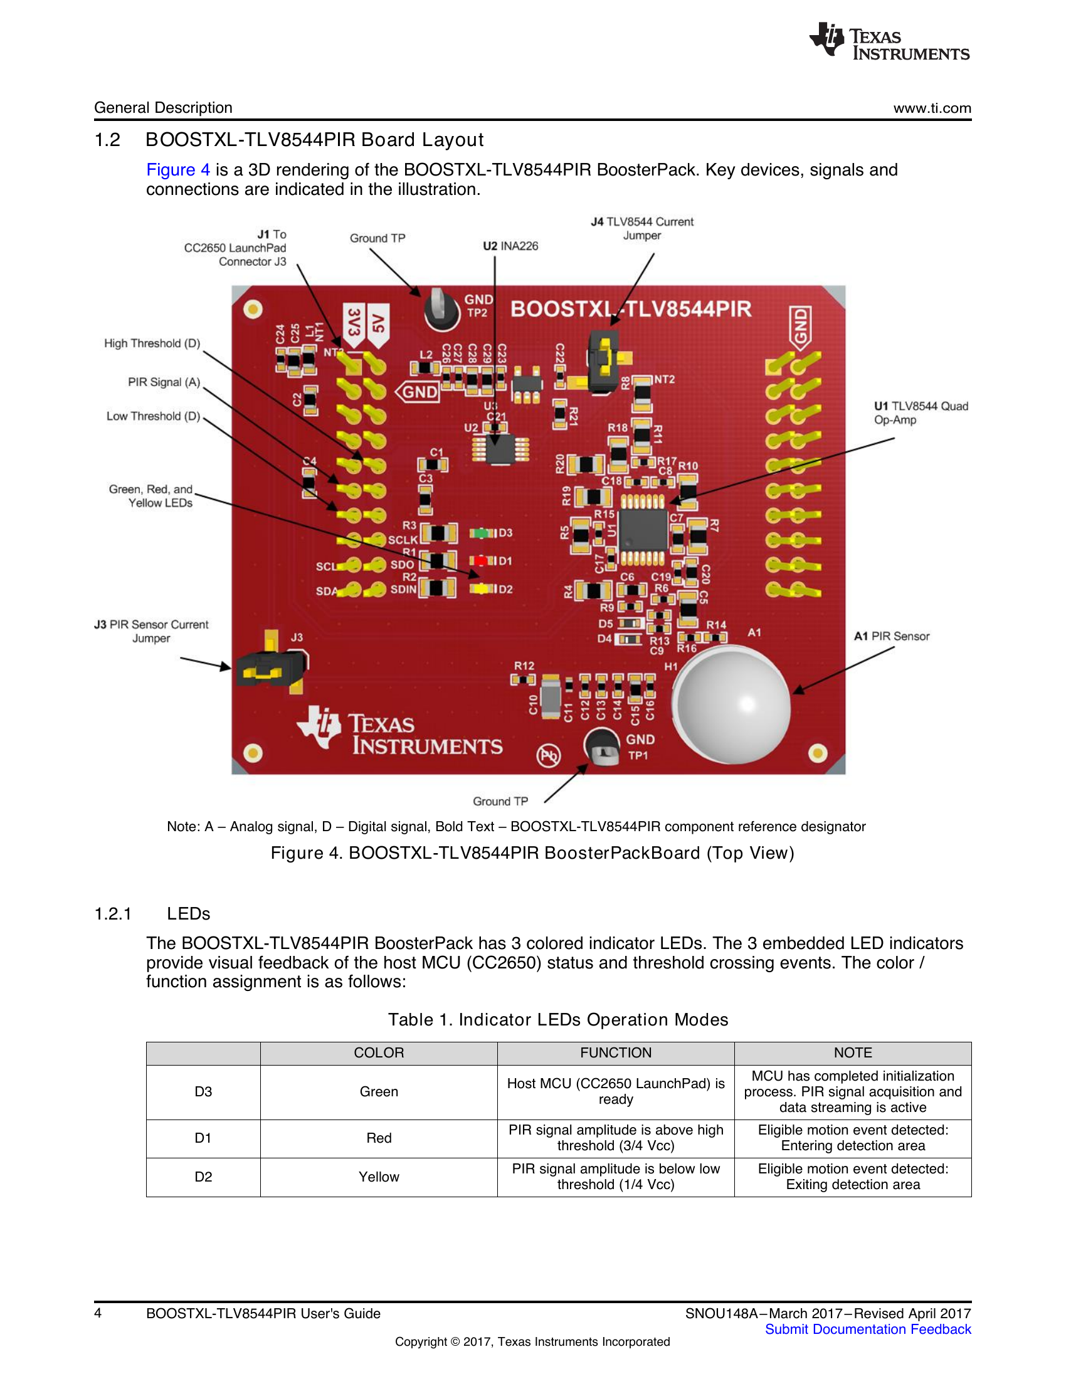
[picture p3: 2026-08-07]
reference/rendered-board/boostxl-tlv8544pir-top-view-04.png

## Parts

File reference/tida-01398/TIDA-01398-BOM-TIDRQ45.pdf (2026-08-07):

TIDA-01398
Variant: | 001 | E1
Generated: 2/22/2017 1:00:14 PM
TID #: | TIDA-01398 | TIDA-01398 REV E1 Bill of Materials
Item # | Designator | Quantity | Value | PartNumber | Manufacturer | Description | PackageReference
1 | !PCB1 | 1 | | TIDA-01398 | Any | Printed Circuit Board
2 | A1 | 1 | 3.6mVp-p | IRS-B210ST01-R1 | MuRata | Pyroelectric Infrared Sensors for Reflow Soldering, 3.6mVp-p, SMD | 4.7x4.7mm
3 | BT1 | 1 | | BS-7 | Memory Protection Devices | Battery Holder, CR2032, Retainer clip, TH | CR2032 holder
4 | C4, C11 | 2 | 10uF | GRM188R60J106ME47D | MuRata | CAP, CERM, 10 µF, 6.3 V, +/- 20%, X5R, 0603 | 0603
5 | C5, C6 | 2 | 12pF | GRM1555C1E120JA01D | MuRata | CAP, CERM, 12 pF, 25 V, +/- 5%, C0G/NP0, 0402 | 0402
6 | C7, C8, C9, C10 | 4 | 0.1uF | GRM155R70J104KA01D | MuRata | CAP, CERM, 0.1 µF, 6.3 V, +/- 10%, X7R, 0402 | 0402
7 | C13 | 1 | 0.1uF | GRM188R71E104KA01D | MuRata | CAP, CERM, 0.1 µF, 25 V, +/- 10%, X7R, 0603 | 0603
8 | C14 | 1 | 1uF | GRM155R61A105KE15D | MuRata | CAP, CERM, 1 µF, 10 V, +/- 10%, X5R, 0402 | 0402
9 | C15, C16 | 2 | 1.2pF | GRM1555C1H1R2BA01D | MuRata | CAP, CERM, 1.2 pF, 50 V, +/- 8.3%, C0G/NP0, 0402 | 0402
10 | C17 | 1 | 12pF | GRM1555C1H120JA01D | MuRata | CAP, CERM, 12 pF, 50 V, +/- 5%, C0G/NP0, 0402 | 0402
11 | C18, C20 | 2 | 2200pF | C1005X7R1H222K | TDK | CAP, CERM, 2200 pF, 50 V, +/- 10%, X7R, 0402 | 0402
12 | C21, C22 | 2 | 100uF | C3216X5R1A107M160AC | TDK | CAP, CERM, 100 µF, 10 V, +/- 20%, X5R, 1206_190 | 1206_190
13 | C23 | 1 | 10uF | C1608X5R0J106M | TDK | CAP, CERM, 10 µF, 6.3 V, +/- 20%, X5R, 0603 | 0603
14 | C24 | 1 | 10uF | GRM155R60J106ME44D | MuRata | CAP, CERM, 10 µF, 6.3 V, +/- 20%, X5R, 0402 | 0402
15 | C25 | 1 | 1uF | C1608X7R1C105K | TDK | CAP, CERM, 1 µF, 16 V, +/- 10%, X7R, 0603 | 0603
16 | C26 | 1 | 1uF | C1005X5R1A105K050BB | TDK | CAP, CERM, 1 µF, 10 V, +/- 10%, X5R, 0402 | 0402
17 | C27, C28 | 2 | 0.1uF | C1005X7R1H104K050BB | TDK | CAP, CERM, 0.1 µF, 50 V, +/- 10%, X7R, 0402 | 0402
18 | C29, C30 | 2 | 0.01uF | C1005X7R1C103K050BA | TDK | CAP, CERM, 0.01 µF, 16 V, +/- 10%, X7R, 0402 | 0402
19 | C31, C37 | 2 | 1000pF | C1005X7R1H102K | TDK | CAP, CERM, 1000 pF, 50 V, +/- 10%, X7R, 0402 | 0402
20 | C32 | 1 | 100pF | C0402C101J3GACTU | Kemet | CAP, CERM, 100 pF, 25 V, +/- 5%, C0G/NP0, 0402 | 0402
21 | C33 | 1 | 33uF | C2012X5R1A336M125AC | TDK | CAP, CERM, 33 µF, 10 V, +/- 20%, X5R, 0805 | 0805
22 | C34 | 1 | 0.01uF | C1005X7R1E103K | TDK | CAP, CERM, 0.01 µF, 25 V, +/- 10%, X7R, 0402 | 0402
23 | C35, C38, C46, C47 | 4 | 0.1uF | C1005X7R1H104K | TDK | CAP, CERM, 0.1 µF, 50 V, +/- 10%, X7R, 0402 | 0402
24 | C36 | 1 | 3.3uF | C1005X5R1A335K050BC | TDK | CAP, CERM, 3.3 µF, 10 V, +/- 10%, X5R, 0402 | 0402
25 | C41 | 1 | 1000pF | C1005C0G1E102J | TDK | CAP, CERM, 1000 pF, 25 V, +/- 5%, C0G/NP0, 0402 | 0402
26 | D1, D2 | 2 | 75V | 1N4148X-TP | Micro Commercial Components | Diode, Switching, 75 V, 0.3 A, SOD-523 | SOD-523
27 | E1 | 1 | | ANTENNA_DN007A | N/A | 2.4GHz PCB Antenna. There is nothing to buy or mount. | SMD, 3-Leads
28 | H1, H3, H5, H7 | 4 | | 1902C | Keystone | Standoff, Hex, 0.5"L #4-40 Nylon | Standoff
29 | H2, H4, H6, H8 | 4 | | NY PMS 440 0025 PH | B&F Fastener Supply | Machine Screw, Round, #4-40 x 1/4, Nylon, Philips panhead | Screw
30 | H9 | 1 | | IML-0669 | MuRata | Lens, Ceiling Mount, TH | D12xH8.508mm
31 | J1 | 1 | | GRPB052VWVN-RC | Sullins Connector Solutions | Header, 50mil, 5x2, Gold, TH | Header, 5x2, 50mil
32 | J3 | 1 | | TSW-102-07-G-S | Samtec | Header, 100mil, 2x1, Gold, TH | 2x1 Header
33 | J5, J6 | 2 | | 87898-0204 | Molex | Header, 2.54 mm, 2x1, Gold, R/A, SMT | Header, 2.54 mm, 2x1, R/A, SMT
34 | L1 | 1 | 1500 ohm | BLM18HE152SN1D | MuRata | Ferrite Bead, 1500 ohm @ 100 MHz, 0.5 A, 0603 | 0603
35 | L2 | 1 | 10uH | CKS2125100M-T | Taiyo Yuden | Inductor, Multilayer, Ferrite, 10uH, 0.11A, 0.52 ohm, SMD | 0805
36 | L3 | 1 | 15nH | LQG15HS15NJ02D | MuRata | Inductor, Multilayer, Air Core, 15 nH, 0.3 A, 0.32 ohm, SMD | 0402 polarized
37 | L4 | 1 | 2nH | LQG15HS2N0S02D | MuRata | Inductor, Multilayer, Air Core, 2 nH, 0.3 A, 0.1 ohm, SMD | 0402 polarized
38 | Q1, Q2 | 2 | -20V | SI2323DS | Vishay-Siliconix | MOSFET, P-CH, -20 V, -3.7 A, SOT-23 | SOT-23
39 | R1, R5, R6, R10, R16, R17 | 6 | 0 | CRCW04020000Z0ED | Vishay-Dale | RES, 0, 5%, 0.063 W, 0402 | 0402
40 | R2 | 1 | 100k | CRCW0402100KFKED | Vishay-Dale | RES, 100 k, 1%, 0.063 W, 0402 | 0402
41 | R3, R7 | 2 | 47.5k | CRCW040247K5FKED | Vishay-Dale | RES, 47.5 k, 1%, 0.063 W, 0402 | 0402
42 | R9 | 1 | 619k | CRCW0402619KFKED | Vishay-Dale | RES, 619 k, 1%, 0.063 W, 0402 | 0402
43 | R11 | 1 | 6.81k | CRCW04026K81FKED | Vishay-Dale | RES, 6.81 k, 1%, 0.063 W, 0402 | 0402
44 | R12 | 1 | 1.30Meg | CRCW04021M30FKED | Vishay-Dale | RES, 1.30 M, 1%, 0.063 W, 0402 | 0402
45 | R13 | 1 | 1.50Meg | CRCW04021M50FKED | Vishay-Dale | RES, 1.50 M, 1%, 0.063 W, 0402 | 0402
46 | R14 | 1 | 68.1k | CRCW040268K1FKED | Vishay-Dale | RES, 68.1 k, 1%, 0.063 W, 0402 | 0402
47 | R15, R18, R19, R20, R21 | 5 | 15Meg | RMCF0805JT15M0 | Stackpole Electronics Inc | RES, 15 M, 5%, 0.125 W, AEC-Q200 Grade 0, 0805 | 0805
48 | S1, S2 | 2 | | B3U-1000P | Omron Electronic Components | SWITCH TACTILE SPST-NO 0.05A 12V | 3x1.6x2.5mm
49 | SH-J1, SH-J2, SH-J3 | 3 | 1x2 | 969102-0000-DA | 3M | Shunt, 100mil, Gold plated, Black | Shunt
50 | TP1, TP2, TP5 | 3 | SMT | 5015 | Keystone | Test Point, Miniature, SMT | Testpoint_Keystone_ Miniature
51 | TP3, TP4 | 2 | Black | 5001 | Keystone | Test Point, Miniature, Black, TH | Black Miniature Testpoint
52 | TP6, TP7 | 2 | Yellow | 5004 | Keystone | Test Point, Miniature, Yellow, TH | Yellow Miniature Testpoint
53 | U1 | 1 | | CC2650F128RSMR | Texas Instruments | Ultra low-power ARM Cortex M3 2.4 GHz Radio MCU, RSM0032B | RSM0032B
54 | U2, U3, U4, U5 | 4 | | TPD1E10B06DPYR | Texas Instruments | ESD in 0402 Package with 10 pF Capacitance and 6 V Breakdown, 1 Channel, -40 to +125 degC, 2-pin X2SON (DPY), Green (RoHS & no Sb/Br) | DPY0002A
55 | U6 | 1 | | TLV8544PWR | Texas Instruments | 500 nA RRIO Nanopower Operational Amplifier, PW0014A (TSSOP-14) | PW0014A
56 | Y1 | 1 | | TSX-3225 24.0000MF20G-AC3 | Epson | Crystal, 24 MHz, 9 pF, SMD | SMD, 4-Leads, Body 2.65x3.35mm, Height 0.6mm
57 | Y2 | 1 | | FC-12M 32.7680KA-A3 | Epson | Crystal, 32.768kHz, 12.5pF, SMD | Crystal 2.05x.6x1.2mm
58 | C1, C2 | 0 | 12pF | GRM1555C1E120JA01D | MuRata | CAP, CERM, 12 pF, 25 V, +/- 5%, C0G/NP0, 0402 | 0402
59 | C3 | 0 | | Used in BOM report | Used in BOM report | CAP, CERM, xxxF, xxV, [TempCo], xx%, [PackageReference] | 0603
60 | C12, C19, C48 | 0 | | Used in BOM report | Used in BOM report | CAP, CERM, xxxF, xxV, [TempCo], xx%, [PackageReference] | 0402
61 | FID1, FID2, FID3, FID4, FID5, FID6 | 0 | | N/A | N/A | Fiducial mark. There is nothing to buy or mount. | N/A
62 | J2 | 0 | | TSW-106-07-G-S | Samtec | Header, 100mil, 6x1, Gold, TH | 6x1 Header
63 | J4 | 0 | | CONSMA001-SMD-G | Linx Technologies | Jack, SMA, PCB, Gold, SMT | SMA Jack
64 | R4 | 0 | 0 | CRCW04020000Z0ED | Vishay-Dale | RES, 0, 5%, 0.063 W, 0402 | 0402

# IMPORTANT NOTICE FOR TI DESIGN INFORMATION AND RESOURCES

Texas Instruments Incorporated (‘TI”) technical, application or other design advice, services or information, including, but not limited to, reference designs and materials relating to evaluation modules, (collectively, “TI Resources”) are intended to assist designers who are developing applications that incorporate TI products; by downloading, accessing or using any particular TI Resource in any way, you (individually or, if you are acting on behalf of a company, your company) agree to use it solely for this purpose and subject to the terms of this Notice.
TI’s provision of TI Resources does not expand or otherwise alter TI’s applicable published warranties or warranty disclaimers for TI products, and no additional obligations or liabilities arise from TI providing such TI Resources. TI reserves the right to make corrections, enhancements, improvements and other changes to its TI Resources.
You understand and agree that you remain responsible for using your independent analysis, evaluation and judgment in designing your applications and that you have full and exclusive responsibility to assure the safety of your applications and compliance of your applications (and of all TI products used in or for your applications) with all applicable regulations, laws and other applicable requirements. You represent that, with respect to your applications, you have all the necessary expertise to create and implement safeguards that (1) anticipate dangerous consequences of failures, (2) monitor failures and their consequences, and (3) lessen the likelihood of failures that might cause harm and take appropriate actions. You agree that prior to using or distributing any applications that include TI products, you will thoroughly test such applications and the functionality of such TI products as used in such applications. TI has not conducted any testing other than that specifically described in the published documentation for a particular TI Resource.
You are authorized to use, copy and modify any individual TI Resource only in connection with the development of applications that include the TI product(s) identified in such TI Resource. NO OTHER LICENSE, EXPRESS OR IMPLIED, BY ESTOPPEL OR OTHERWISE TO ANY OTHER TI INTELLECTUAL PROPERTY RIGHT, AND NO LICENSE TO ANY TECHNOLOGY OR INTELLECTUAL PROPERTY RIGHT OF TI OR ANY THIRD PARTY IS GRANTED HEREIN, including but not limited to any patent right, copyright, mask work right, or other intellectual property right relating to any combination, machine, or process in which TI products or services are used. Information regarding or referencing third-party products or services does not constitute a license to use such products or services, or a warranty or endorsement thereof. Use of TI Resources may require a license from a third party under the patents or other intellectual property of the third party, or a license from TI under the patents or other intellectual property of TI.
TI RESOURCES ARE PROVIDED “AS IS” AND WITH ALL FAULTS. TI DISCLAIMS ALL OTHER WARRANTIES OR REPRESENTATIONS, EXPRESS OR IMPLIED, REGARDING TI RESOURCES OR USE THEREOF, INCLUDING BUT NOT LIMITED TO ACCURACY OR COMPLETENESS, TITLE, ANY EPIDEMIC FAILURE WARRANTY AND ANY IMPLIED WARRANTIES OF MERCHANTABILITY, FITNESS FOR A PARTICULAR PURPOSE, AND NON-INFRINGEMENT OF ANY THIRD PARTY INTELLECTUAL PROPERTY RIGHTS.
TI SHALL NOT BE LIABLE FOR AND SHALL NOT DEFEND OR INDEMNIFY YOU AGAINST ANY CLAIM, INCLUDING BUT NOT LIMITED TO ANY INFRINGEMENT CLAIM THAT RELATES TO OR IS BASED ON ANY COMBINATION OF PRODUCTS EVEN IF DESCRIBED IN TI RESOURCES OR OTHERWISE. IN NO EVENT SHALL TI BE LIABLE FOR ANY ACTUAL, DIRECT, SPECIAL, COLLATERAL, INDIRECT, PUNITIVE, INCIDENTAL, CONSEQUENTIAL OR EXEMPLARY DAMAGES IN CONNECTION WITH OR ARISING OUT OF TI RESOURCES OR USE THEREOF, AND REGARDLESS OF WHETHER TI HAS BEEN ADVISED OF THE POSSIBILITY OF SUCH DAMAGES.
You agree to fully indemnify TI and its representatives against any damages, costs, losses, and/or liabilities arising out of your non-compliance with the terms and provisions of this Notice.
This Notice applies to TI Resources. Additional terms apply to the use and purchase of certain types of materials, TI products and services. These include; without limitation, TI’s standard terms for semiconductor products http://www.ti.com/sc/docs/stdterms.htm), evaluation modules, (http://www.ti.com/lit/pdf/SSZZ027) and samples (http://www.ti.com/sc/docs/sampterms.htm).

## Mailing Address: Texas Instruments, Post Office Box 655303, Dallas, Texas 75265 Copyright © 2017, Texas Instruments Incorporated

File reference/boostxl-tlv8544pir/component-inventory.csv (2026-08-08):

reference | quantity | value_or_part | role | confidence
U1 | 1 | TLV8544PWR | Quad nanopower op amp for gain filtering and window comparison | high
U2 | 1 | INA226AIDGSR | I2C current and power monitor | high
U3 | 1 | Not printed | Five-pin unity-gain buffer in current-measurement path | low
A1 | 1 | IRS-B210ST01-R1 | Passive infrared sensing element; cross-identified from related TI BOM and E2E evidence | medium-high
H1 | 1 | IML-0669 | PIR lens | high
J1 J2 | 2 | SSQ-110-03-G-D | LaunchPad 1x10 female headers | high
J3 J4 | 2 | 87898-0204 | Two-pin current-measurement jumper headers | high
L1 L2 | 2 | BLM18HE152SN1D | 1500-ohm ferrite beads | high
NT1 NT2 NT3 | 3 | Net tie | Power-rail configuration links | high
TP1 TP2 | 2 | Ground test point | Instrumentation ground points | high
D1 | 1 | Red LED | High-threshold indicator | high
D2 | 1 | Yellow LED | Low-threshold indicator | high
D3 | 1 | Green LED | Host-ready indicator | high
D4 D5 | 2 | 1N4148X-TP | Small-signal clamp diodes | high
R1 | 1 | 442 ohm 1% 0.125 W | Red LED current limit | high
R2 R3 | 2 | 487 ohm 1% 0.125 W | Yellow and green LED current limit | high
R4 R5 R10 R19 | 4 | 10.0 kohm | Analog output isolation resistors | high
R6 | 1 | 6.81 kohm | First amplifier feedback network | high
R7 R8 R11 R18 R20 | 5 | 15 Mohm | Gain and reference-divider network | high
R9 | 1 | 1.50 Mohm | First amplifier feedback network | high
R12 | 1 | 619 kohm | PIR sensor bias | high
R13 | 1 | 68.1 kohm | Second amplifier input network | high
R14 R15 R17 | 3 | 0 ohm | Configuration links | high
R16 | 1 | 1.30 Mohm | First amplifier bias network | high
R21 | 1 | 15.0 kohm 0.1% | TLV8544 supply-current shunt | high
C1 C2 C3 C4 | 4 | 0.01 uF | LaunchPad signal filtering | high
C5 | 1 | 33 uF | First amplifier feedback filter | high
C6 | 1 | 0.01 uF | First amplifier feedback filter | high
C7 C15 | 2 | 1000 pF | Analog filtering | high
C8 C13 C17 C18 C19 C21 C23 | 7 | 0.1 uF | Reference and supply decoupling | high
C22 | 1 | 0.1 uF | Filtering across the R21 TLV supply-current shunt | high
C9 | 1 | 3.3 uF | Interstage AC coupling | high
C10 | 1 | 100 uF | PIR supply filtering | high
C11 C20 | 2 | 10 uF | Supply and signal filtering | high
C12 | 1 | 1 uF | PIR supply filtering | high
C14 | 1 | 0.01 uF | PIR supply filtering | high
C16 | 1 | 100 pF | PIR supply filtering | high
C24 C26 C27 | 3 | 0.1 uF 6.3 V X7R | LaunchPad supply filtering | high
C25 C28 | 2 | 10 uF 6.3 V X5R | LaunchPad supply filtering | high
C29 | 1 | 0.1 uF 25 V X7R | 5-V LaunchPad supply filtering | high

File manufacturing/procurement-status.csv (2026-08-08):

category | designators | manufacturer | manufacturer_part_number | JLCPCB_part_number | package_or_footprint | status | required_action
op_amp | U1 | Texas Instruments | TLV8544PWR | C2867322 | TSSOP-14 | exact_jlc_part | Reconfirm stock and assembly tier
current_monitor | U2 | Texas Instruments | INA226AIDGSR | C49851 | VSSOP-10 | exact_jlc_part | Reconfirm stock and assembly tier
buffer_op_amp | U3 | Texas Instruments | TLV333IDBVR | C473369 | SOT-23-5 | qualified_substitute | Validate INA226 reading against calibrated ammeter
pir_sensor | A1 | Murata | IRA-S210ST01 | C152563 | Exact imported 3-lead THT footprint | qualified_substitute | Reconfirm stock and wave-solder fixture or hand-install plan
pir_lens | H1 | Murata | IML-0688 |  | 10.8 mm square mechanical envelope | matched_mechanical_part | Source separately and validate housing alignment and retention
switching_diode | D4 D5 | Micro Commercial Components | 1N4148X-TP | C507292 | SOD-523 | exact_jlc_part | Reconfirm stock and polarity
ferrite_bead | L1 L2 | Murata | BLM18HE152SN1D | C82155 | 0603 | exact_jlc_part | Reconfirm stock
boosterpack_headers | J1 J2 | Samtec | SSQ-110-03-G-D | C3323139 | Exact imported 2x10 THT | exact_jlc_part | Reconfirm G-D variant stock and mating height
current_jumpers | J3 J4 | DEALON | DZ254S-11-02-48 | C5160785 | Exact imported 1x2 2.54 mm vertical SMT with 6 mm upright pins | selected_jlc_replacement | Verify shunt fit and upright clearance
jumper_shunts | SH-J3 SH-J4 | BOOMELE | 2.54Short Circuit Cap Opening | C5305 | 1x2 2.54 mm removable shunt | mechanical_assembly_item | Fit after assembly and remove only when inserting an ammeter
testpoints | TP1 TP2 | Keystone | 5001 | C238122 | Exact imported THT test point | exact_jlc_part | Confirm probe compatibility and wave-solder process
resistor | R1 | Yageo | AC0805FR-07442RL | C228838 | 0805 442 ohm 1% 0.125 W | selected_jlc_part | Reconfirm stock
resistor | R2 R3 | Stackpole | RMCS0805FT487R | C7289906 | 0805 487 ohm 1% 0.125 W | selected_jlc_part | Reconfirm stock
resistor | R4 R5 R10 R19 | UniOhm | CQ03WAF1002T5E | C516551 | 0603 10 kohm 1% | selected_jlc_part | Reconfirm stock
resistor | R6 | SAE | 1RC0603F6811 | C54531559 | 0603 6.81 kohm 1% | selected_jlc_part | Reconfirm stock
resistor | R7 R8 R11 R18 R20 | VO | SCR0805F15M | C3016870 | 0805 15 Mohm 1% 150 V | selected_jlc_part | Clean flux and verify leakage control
resistor | R9 | SAE | 1RC0603F1504 | C54531218 | 0603 1.50 Mohm 1% | selected_jlc_part | Reconfirm stock
resistor | R12 | Yageo | RC0603FR-07619KL | C245988 | 0603 619 kohm 1% | selected_jlc_part | Reconfirm stock
resistor | R13 | KOA Speer | RK73H1JTTD6812F | C830353 | 0603 68.1 kohm 1% | selected_jlc_part | Reconfirm stock
resistor | R14 R15 R17 NT1 NT2 NT3 | UniOhm | 0603WAF0000T5E | C21189 | 0603 0 ohm | selected_jlc_part | Reconfirm stock
resistor | R16 | SAE | 1RC0603F1304 | C54531191 | 0603 1.30 Mohm 1% | selected_jlc_part | Reconfirm stock
resistor | R21 | Yageo | RT0603BRD0715KL | C326733 | 0603 15.0 kohm 0.1% | selected_jlc_part | Validate current measurement calibration
capacitor | C1 C2 C3 C4 C6 C14 | Murata | GRM188R71H103KA01D | C77053 | 0603 0.01 uF 50 V X7R | selected_jlc_part | Reconfirm stock
capacitor | C5 | TDK | C2012X5R1A336MTJ00E | C342635 | 0805 33 uF 10 V X5R | selected_jlc_part | Check effective capacitance under DC bias
capacitor | C7 C15 | Murata | GRM1885C1H102JA01D | C77026 | 0603 1000 pF 50 V C0G | selected_jlc_part | Reconfirm stock
capacitor | C8 C13 C17 C18 C19 C21 C22 C23 C24 C26 C27 C29 | Murata | GRM188R71E104KA01D | C77050 | 0603 0.1 uF 25 V X7R | selected_jlc_part | Reconfirm stock
capacitor | C9 | TDK | C2012X5R1A335M125AA | C3851074 | 0805 3.3 uF 10 V X5R | selected_jlc_part | Check effective capacitance under DC bias
capacitor | C10 | HRE | CGA1206X5R107M100NT | C6119961 | 1206 100 uF 10 V X5R | selected_jlc_part | Verify vendor data and effective capacitance under DC bias
capacitor | C11 C20 C25 C28 | Murata | GRM188R60J106ME47D | C77041 | 0603 10 uF 6.3 V X5R | selected_jlc_part | Reconfirm stock and effective capacitance
capacitor | C12 | TDK | C1608X7R1C105KT000N | C76617 | 0603 1 uF 16 V X7R | selected_jlc_part | Reconfirm stock
capacitor | C16 | Murata | GRM1885C1H101JA01D | C71664 | 0603 100 pF 50 V C0G | selected_jlc_part | Reconfirm stock
indicator_led | D1 | Everlight | 19-217/R6C-AL1M2VY/3T | C72044 | 0603 red | selected_jlc_part | Verify polarity and brightness
indicator_led | D2 | Everlight | 19-213/Y2C-CQ2R2L/3T(CY) | C72038 | 0603 yellow | selected_jlc_part | Verify polarity and brightness
indicator_led | D3 | Everlight | 19-217/G7C-AN1P2/6T | C2986030 | 0603 yellow-green | selected_jlc_part | Verify polarity and brightness

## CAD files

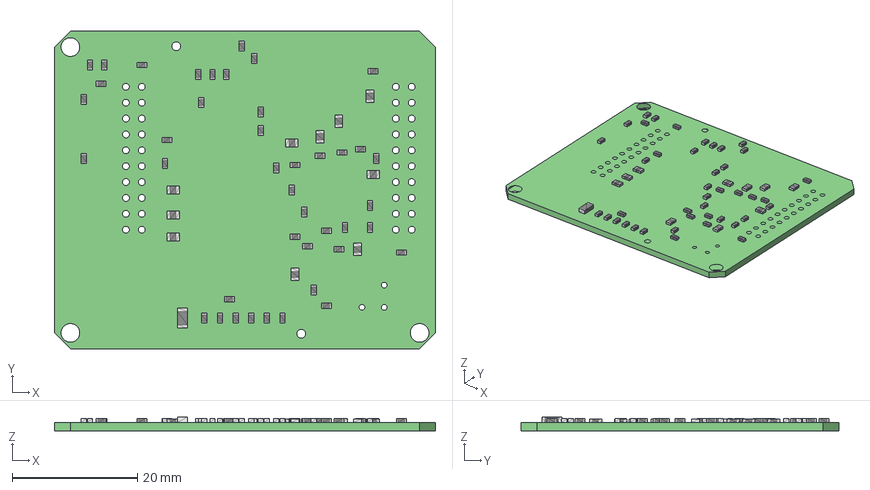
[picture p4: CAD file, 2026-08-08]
exports/BOOSTXL-TLV8544PIR.step
61.0 x 50.8 x 2.30 mm

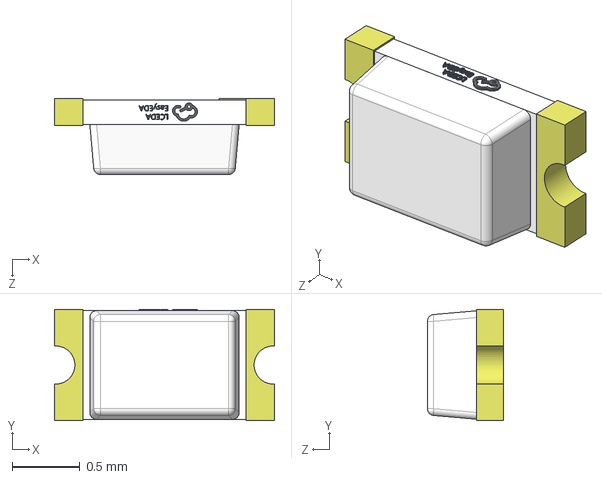
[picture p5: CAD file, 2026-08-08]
imports/A_19_213_Y2C_CQ2R2L_3T_CY_/A_19_213_Y2C_CQ2R2L_3T_CY_.step
1.62 x 0.82 x 0.56 mm

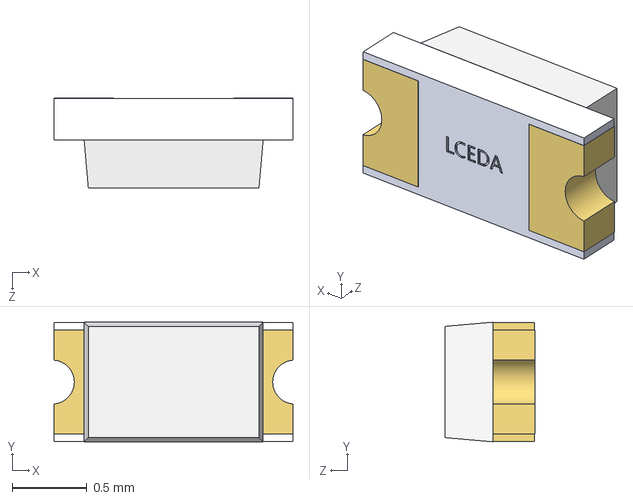
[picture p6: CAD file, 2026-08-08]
imports/A_19_217_G7C_AN1P2_6T/A_19_217_G7C_AN1P2_6T.step
1.60 x 0.802 x 0.601 mm

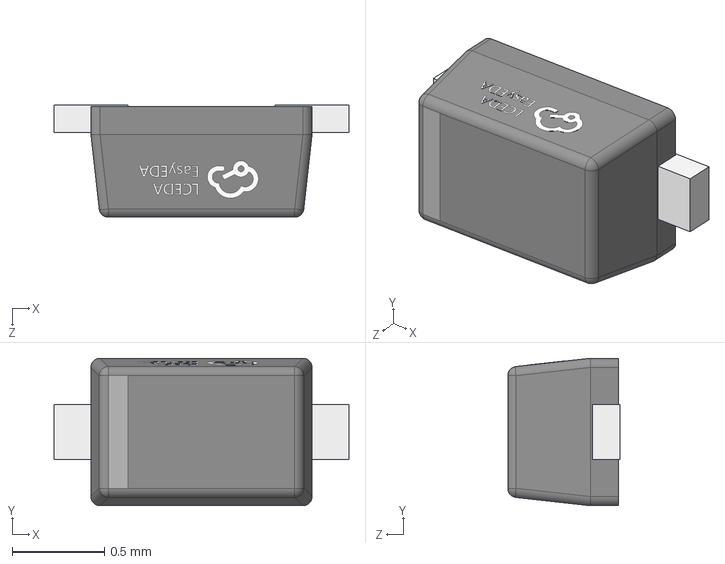
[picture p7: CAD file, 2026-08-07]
imports/A_1N4148X_TP/A_1N4148X_TP.step
1.60 x 0.8 x 0.61 mm

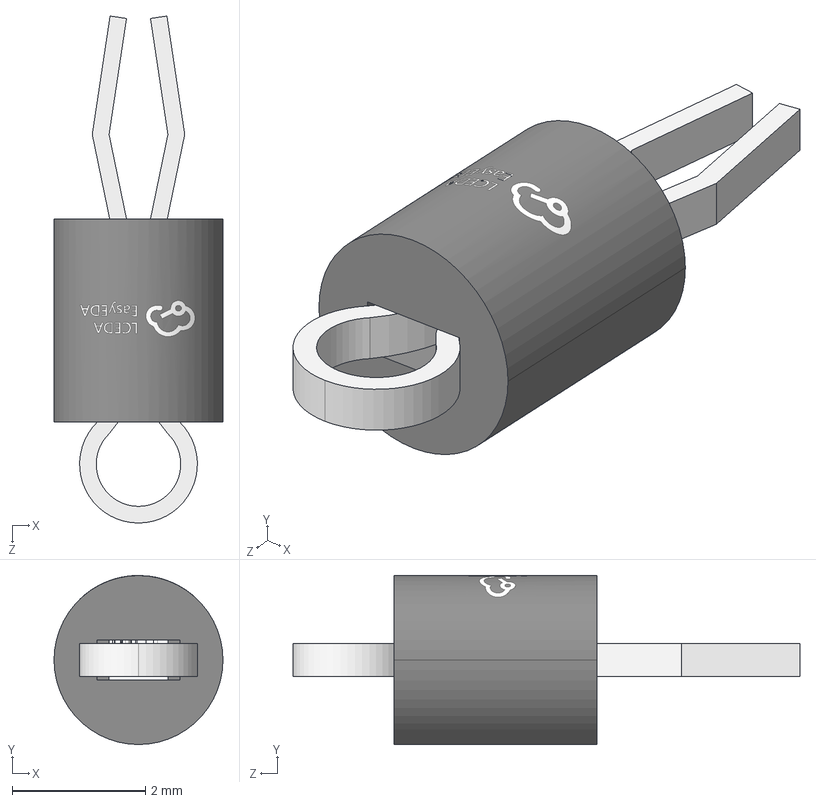
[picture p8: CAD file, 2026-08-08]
imports/A_5001/A_5001.step
2.54 x 2.54 x 7.62 mm

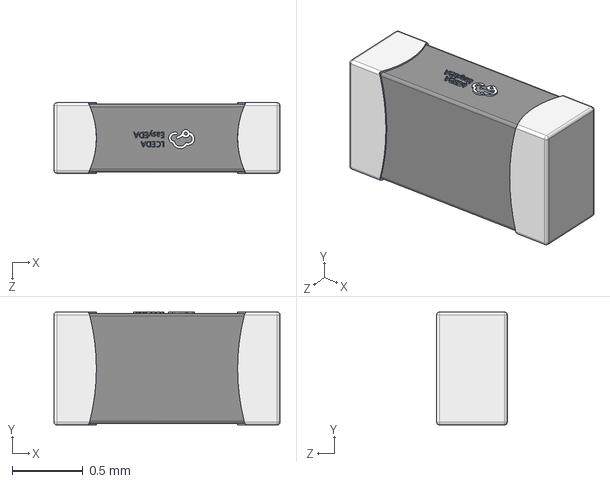
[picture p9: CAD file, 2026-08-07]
imports/BLM18HE152SN1D/BLM18HE152SN1D.step
1.60 x 0.8 x 0.5 mm

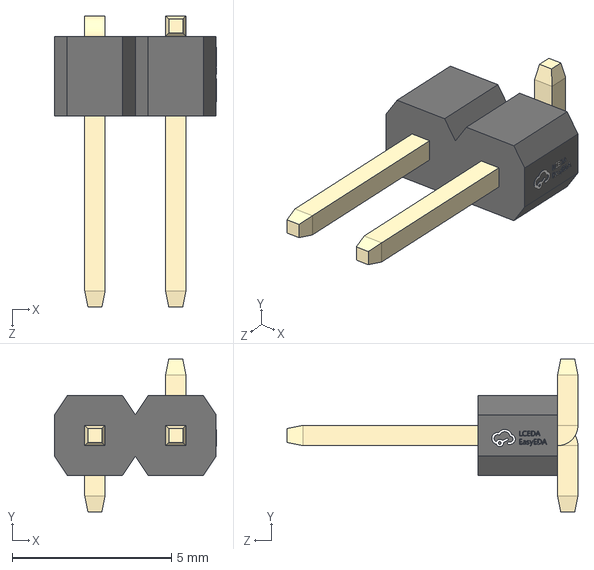
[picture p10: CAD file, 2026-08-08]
imports/DZ254S_11_02_48/DZ254S_11_02_48.step
5.09 x 4.80 x 9.14 mm

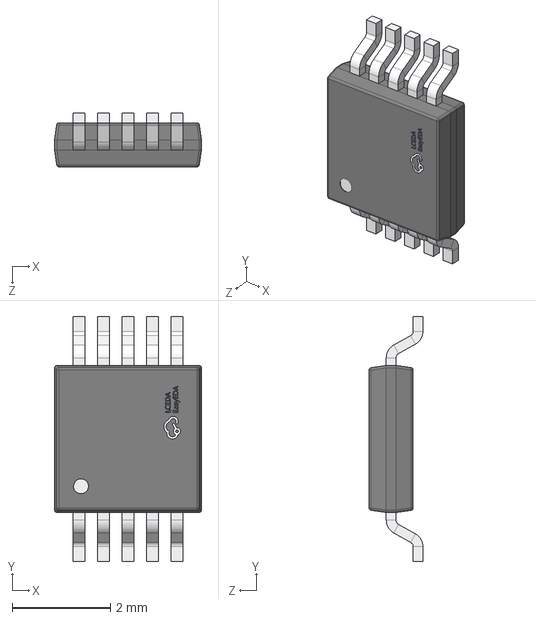
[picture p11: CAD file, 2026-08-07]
imports/INA226AIDGSR/INA226AIDGSR.step
3.00 x 5.00 x 1.10 mm

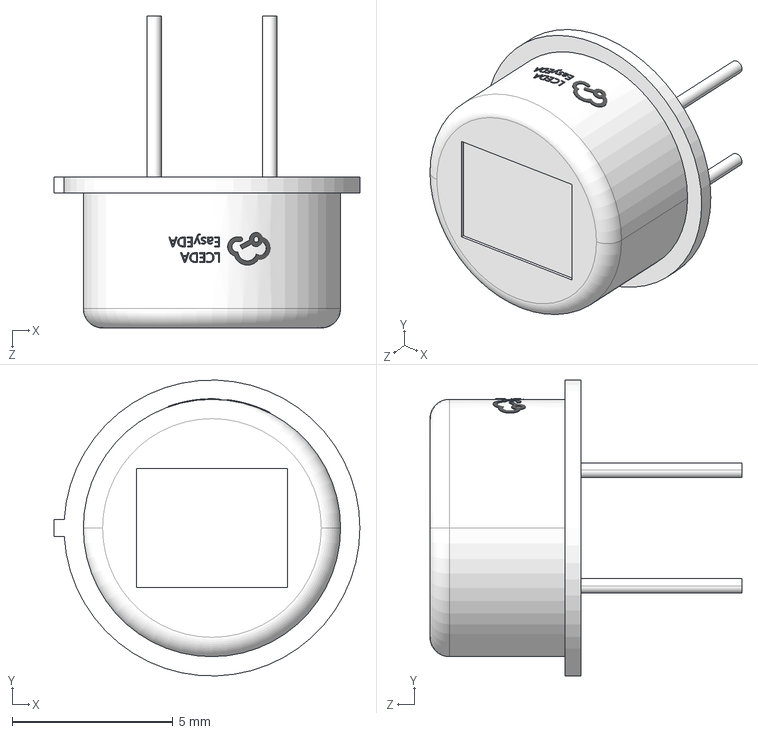
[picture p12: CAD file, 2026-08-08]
imports/IRA_S210ST01/IRA_S210ST01.step
9.51 x 9.20 x 9.70 mm

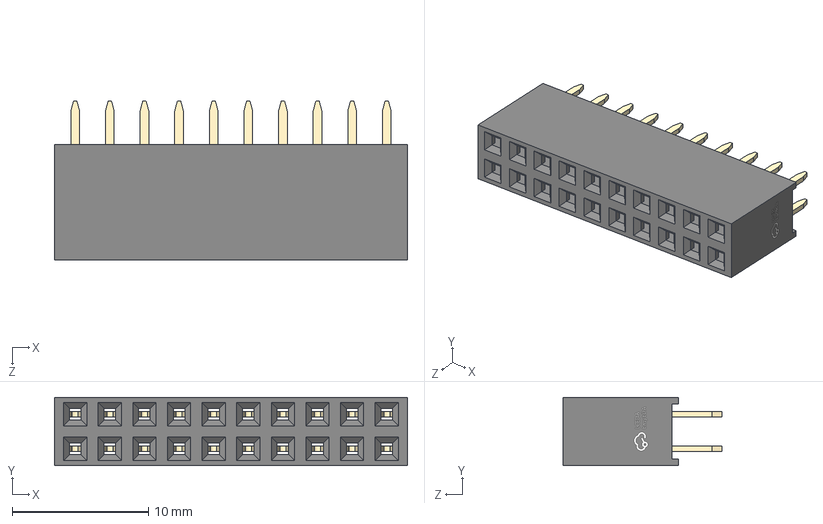
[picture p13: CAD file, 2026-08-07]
imports/SSQ_110_03_G_D/SSQ_110_03_G_D.step
25.9 x 5.00 x 11.7 mm

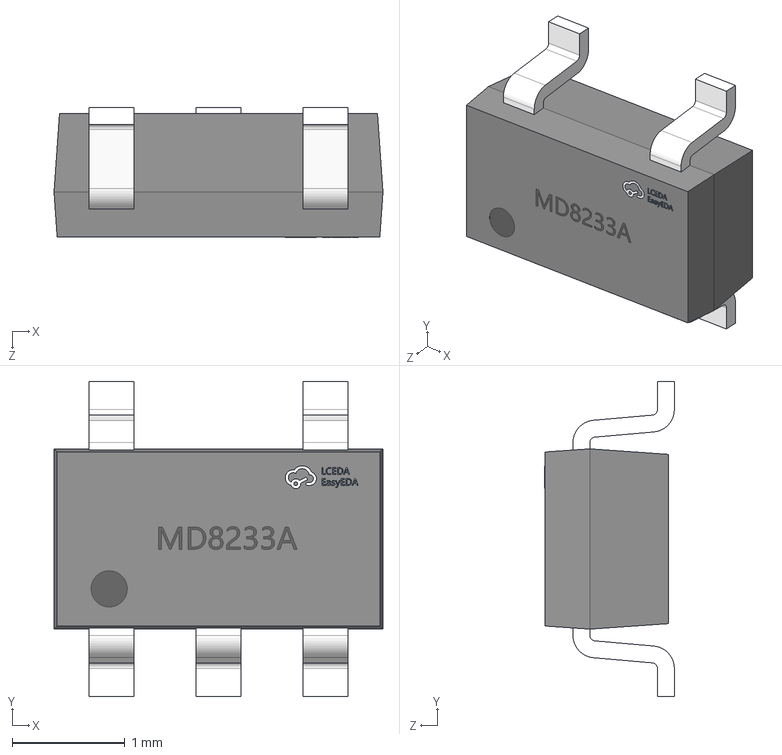
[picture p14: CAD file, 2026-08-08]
imports/TLV333IDBVR/TLV333IDBVR.step
2.92 x 2.80 x 1.15 mm

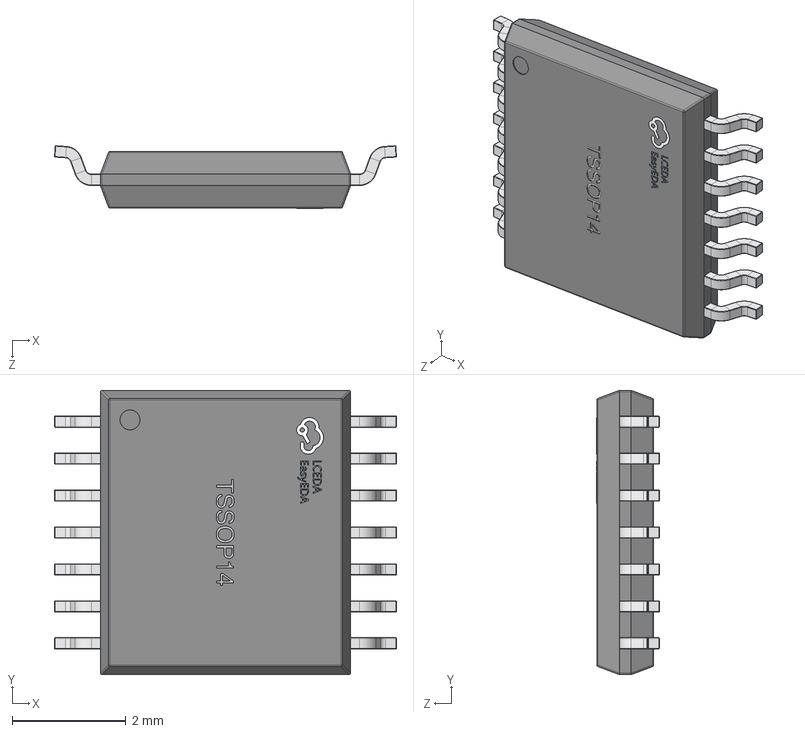
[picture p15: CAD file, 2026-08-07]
imports/TLV8544PWR/TLV8544PWR.step
6.01 x 5.00 x 1.10 mm

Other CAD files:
imports/A_19_217_R6C_AL1M2VY_3T/A_19_217_R6C_AL1M2VY_3T.step
imports/A_19_213_Y2C_CQ2R2L_3T_CY_/A_19_213_Y2C_CQ2R2L_3T_CY_.obj
imports/A_19_217_G7C_AN1P2_6T/A_19_217_G7C_AN1P2_6T.obj
imports/A_19_217_R6C_AL1M2VY_3T/A_19_217_R6C_AL1M2VY_3T.obj
imports/A_1N4148X_TP/A_1N4148X_TP.obj
imports/A_5001/A_5001.obj
imports/BLM18HE152SN1D/BLM18HE152SN1D.obj
imports/DZ254S_11_02_48/DZ254S_11_02_48.obj
imports/INA226AIDGSR/INA226AIDGSR.obj
imports/IRA_S210ST01/IRA_S210ST01.obj
imports/SSQ_110_03_G_D/SSQ_110_03_G_D.obj
imports/TLV333IDBVR/TLV333IDBVR.obj
imports/TLV8544PWR/TLV8544PWR.obj

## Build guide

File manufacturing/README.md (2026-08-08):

# Manufacturing review data

`procurement-status.csv` is the curated, frozen part-resolution ledger. It complements the automatically generated BOM inside the Gerber archive and records the selected electrical ratings, package, MPN, supplier ID, and validation action.

The ledger distinguishes exact imported parts, paper-qualified substitutes, fixed passives/LEDs, separately sourced hardware, and first-article validation actions. There are no remaining `TBD` electrical components.

Supplier inventory changes over time. Reconfirm every LCSC/JLCPCB part number and assembly tier immediately before ordering.

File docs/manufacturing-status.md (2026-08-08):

# Manufacturing status

## Resolved engineering blockers

- The 70-component/40-net electrical design is transcribed from TI SNOU148A Figures 27 and 28.
- C22 is across R21 between `3.3VTLV` and `V+_TLV`; it is not a ground bypass. NT2 and NT3 branch from `3.3VTLV`, matching TI's functional rail split.
- U3 is no longer an unidentified placeholder. `TLV333IDBVR` is documented as a qualified substitute with correct SOT-23-5 pinout, 5-V operation, common-mode range, unity-gain stability, offset, imported model, and JLCPCB ID.
- The obsolete five-pad PIR reconstruction is removed. A1 is Murata `IRA-S210ST01` C152563 using the exact three-lead JLCPCB footprint and model; H1 is its matching `IML-0688` lens.
- Every electrical component has a fixed value, manufacturer part number, and JLCPCB/LCSC ID. All non-resistor/non-capacitor electronic parts are instantiated from exact JLCPCB imports.
- J3/J4 use imported JLCPCB C5160785, a 1×2, 2.54-mm vertical SMT header with upright 6-mm pins like TI's current jumpers; the removable shunts remain separate assembly items.
- The 60.96 mm × 50.8 mm two-layer board routes completely: 131 PCB traces, 117 vias with 0.30-mm drills and 0.45-mm pads, bottom GND pour, and zero generated circuit error elements.
- `bun run release-check` fails if critical topology, MPN coverage, board geometry, routing, compact schematic labels, section-divider clearance, error status, or the Gerber-mode `tsci check shorts` result regresses.
- Registry release `1.0.13` is published at `https://tscircuit.com/abse/boostxl-tlv8544pir`. Its online 3D views use the exact imported OBJ models because the registry upload can time out on larger STEP files; the full STEP files remain in GitHub and the manufacturing exports.

## Prototype release gates

These are evidence-producing checks, not missing design decisions:

1. Print/export the PCB at exactly 1:1 and overlay it on the target LaunchPad or physical TI board. Confirm both 2×10 header rows, three hole centers/diameters, outline/chamfers, USB/antenna clearances, sensor center, and 10.8-mm lens envelope. The outline is image/grid-derived because TI did not publish the original CAD.
2. Design or select a housing that keeps `IML-0688` aligned and retained over `IRA-S210ST01`. Murata explicitly requires tab alignment and external retention against dislocation.
3. Reconfirm live supplier inventory and the JLCPCB assembly process immediately before ordering. A1 is an extended, wave-soldered part and may require a fixture or manual installation.
4. Run the generated KiCad PCB through the chosen fabricator's DRC and inspect copper, solder mask, silkscreen, outline, plated holes, and drill files in an independent Gerber viewer.
5. Order a small first article, then execute `docs/bring-up-plan.md`. In particular, qualify motion sensitivity/false triggers with the substituted PIR/lens and compare INA226 current readings against a calibrated ammeter.

Passing those checks promotes the board from prototype release candidate to a validated hardware revision. Generated Gerbers are provided for review, not as an unconditional production release.

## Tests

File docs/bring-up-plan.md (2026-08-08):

# First-article bring-up and acceptance plan

Use a current-limited bench supply and an ESD-safe bench. Do not fit the board to an expensive LaunchPad until the standalone resistance and current checks pass.

## Before power

- Inspect Gerbers independently and run the fabricator-rule KiCad DRC.
- Verify all polarized/oriented parts: A1 drain/source/ground, U1/U2/U3 pin 1, D1-D5, J1/J2, and the IML-0688 tab direction.
- Check every rail to ground with an ohmmeter; reject an unexplained low resistance.
- Confirm J3 and J4 shunts are installed for normal operation or replaced by ammeters for current measurement.
- Inspect the 15-MΩ network for contamination and flux residue; clean/dry the analog section because surface leakage is comparable to its intended currents.

## Controlled power-up

1. Apply 3.3 V and 5 V from current-limited supplies through the matching header pins. Start with conservative current limits and stop on unexpected current or heating.
2. Confirm `V3P3_FILTERED`, `V3P3_TLV`, `V3P3_REF`, and `V3P3_INA` are approximately 3.3 V; confirm `V5_FILTERED` is approximately 5 V.
3. Measure the equal-resistor ladder: `REF_HIGH` 2.475 V, `REF_MID` 1.650 V, `REF_LOW` 0.825 V. Use tolerance-aware limits and investigate any meaningful ratio error.
4. Confirm U3 has 5 V at pin 5, ground at pin 2, and follower output within the expected offset of `V_POS_TLV`.
5. Read INA226 over I²C, confirm its address pins are grounded, and compare its shunt reading with a calibrated ammeter substituted for J4. Check zero and at least two known loads within the 5.461-µA measurement range.

## Analog/PIR verification

1. With A1 shielded from motion, allow the PIR sensor and high-value networks to settle. Record `PIR_VOUT_RAW`, `PIR_VO`, `U1A_OUT`, `U1B_OUT`, and both comparator outputs.
2. Inject a small isolated signal at `PIR_VO` before relying on the sensor. Verify the approximately 0.708-Hz to 10.61-Hz band and staged gain without driving either op-amp into saturation.
3. Install and align IML-0688 in its retaining housing. Move a warm human target across the designed field of view; verify analog response plus `PIR_OUT_HI`/`PIR_OUT_LO` transitions.
4. Repeat no-motion observation for false triggers while cycling nearby digital activity, radio, lighting, airflow, and supply conditions.
5. Test across the intended temperature and distance range. Tune gain only through a documented revision if the IRA-S210/IML-0688 combination differs materially from the obsolete original sensor.

## Acceptance record

Record board serial/revision, assembly supplier, BOM substitutions, supply currents, all voltage checkpoints, INA226-versus-ammeter error, detection distance/angle, false-trigger duration, temperature, and photos of lens alignment. Production release requires reproducible passing results from the chosen sample size, not just one successful motion event.

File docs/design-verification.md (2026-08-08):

# Design verification basis

## Evidence hierarchy

1. **Electrical topology and values:** exact `BOOSTXL-TLV8544PIR` user guide SNOU148A, Figures 27 and 28.
2. **Package and operating limits:** each selected manufacturer's data sheet.
3. **Purchasing identity and imported geometry:** the recorded JLCPCB/LCSC IDs and exact EasyEDA imports.
4. **Supporting selection evidence:** the related TIDA-01398 BOM and TI E2E engineering response. TIDA-01398 is not treated as native CAD or an exact BOM for this BoosterPack.
5. **Mechanical placement:** TI's official top image scaled from the 2.54-mm BoosterPack header grid. This is explicitly an inference pending a 1:1 physical overlay.

The source uses the exact values printed by TI. Manufacturer part numbers for passives are frozen production selections meeting or exceeding the printed package/rating/dielectric requirements; they are not represented as TI's unpublished original brands.

## Calculated analog checkpoints

| Function | Components | Calculated result | Bring-up use |
| --- | --- | ---: | --- |
| First-stage AC gain | R9 = 1.50 MΩ; R6 = 6.81 kΩ | `1 + R9/R6 = 221.26 V/V` | Verify gain below clipping with a small injected signal. |
| First-stage lower corner | R6 = 6.81 kΩ; C5 = 33 µF | `1/(2πRC) = 0.708 Hz` | Slow motion should pass; DC drift should be rejected. |
| First-stage upper corner | R9 = 1.50 MΩ; C6 = 0.01 µF | `10.61 Hz` | High-frequency noise should roll off. |
| Second-stage midband gain magnitude | R7 = 15.0 MΩ; R13 = 68.1 kΩ | `220.26 V/V` | Verify with signal centered at `REF_MID`. |
| Second-stage lower corner | R13 = 68.1 kΩ; C9 = 3.3 µF | `0.708 Hz` | Matches the first stage. |
| Second-stage upper corner | R7 = 15.0 MΩ; C7 = 1000 pF | `10.61 Hz` | Matches the first stage. |
| Ideal combined midband gain magnitude | both stages | `48,736.6 V/V` | Explains why microvolt PIR changes reach comparator scale and why clean layout matters. |
| Comparator ladder at 3.3 V | four equal 15.0-MΩ resistors | `REF_HIGH = 2.475 V`; `REF_MID = 1.650 V`; `REF_LOW = 0.825 V` | Direct DMM acceptance points. |
| INA226 full-scale current through R21 | R21 = 15.0 kΩ; ±81.92-mV shunt range | `5.461 µA` | Confirms the intended measurement range. |
| TLV333 25 °C max-offset equivalent | 15 µV / 15.0 kΩ | `1.0 nA` | Bound for the U3 substitute's input-referred error. |
| INA226 shunt LSB equivalent | 2.5 µV / 15.0 kΩ | `0.167 nA/LSB` | Resolution checkpoint for current readback. |

The two cascaded stages will clip on normal motion; the ideal combined gain is a small-signal design check, not an expectation of linear full-scale output.

## Critical topology assertions

The automated release check verifies these error-prone details in the generated circuit JSON:

- C22 is connected from `V3P3_TLV` to `V_POS_TLV`, in parallel with R21.
- NT1 feeds `V3P3_TLV`; NT2 and NT3 then feed `V3P3_REF` and `V3P3_INA` from that rail.
- U3 is a 5-V-powered TLV333 follower sensing `V_POS_TLV` and driving INA226 `VIN-`.
- A1 drain, source, and ground map to `PIR_VIN1`, `PIR_VOUT_RAW`, and ground.
- All 70 source components carry MPNs and all automatically assembled parts carry supplier IDs.

## Source files

- `reference/boostxl-tlv8544pir/BOOSTXL-TLV8544PIR-user-guide-SNOU148A.pdf`
- `reference/tida-01398/TIDA-01398-BOM-TIDRQ45.pdf`
- `reference/datasheets/TLV8544-datasheet.pdf`
- `reference/datasheets/INA226-datasheet.pdf`
- `reference/datasheets/IRA-S210ST01-datasheet.pdf`
- `reference/datasheets/IML-0688-datasheet.pdf`
- [TI TLV333 data sheet](https://www.ti.com/lit/ds/symlink/tlv333.pdf)

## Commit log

2026-08-07 Initialize BOOSTXL-TLV8544PIR reconstruction
    [A_1N4148X_TP.obj, A_1N4148X_TP.step, BLM18HE152SN1D.obj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]
2026-08-07 Resolve footprints and route BoosterPack PCB
    [BOOSTXL-TLV8544PIR.step, component-inventory.csv]
2026-08-07 Document U3 evidence and manufacturing readiness
    [procurement-status.csv]
2026-08-08 Flatten board into native tscircuit source
    [BOOSTXL-TLV8544PIR.step]
2026-08-08 Flatten board into native tscircuit source (#1)
    [BOOSTXL-TLV8544PIR.step]
2026-08-08 Qualify orderable PIR BoosterPack prototype
    [BOOSTXL-TLV8544PIR.step, IRA_S210ST01.obj, IRA_S210ST01.step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]
2026-08-08 Import all non-passives from JLCPCB
    [A_19_213_Y2C_CQ2R2L_3T_CY_.obj, A_19_213_Y2C_CQ2R2L_3T_CY_.step, A_19_217_G7C_AN1P2_6T.obj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]
2026-08-08 Enforce routed short-circuit check
2026-08-08 Use vertical JLCPCB current jumpers
    [BOOSTXL-TLV8544PIR.step, DZ254S_11_02_48.obj, DZ254S_11_02_48.step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]
2026-08-08 Rework schematic to match TI reference
2026-08-08 Use native schematic sections
2026-08-08 Compact and center schematic sections
2026-08-09 Split schematic into focused sheets (#2)
    * Fix ferrite bead schematic symbols
    * Publish package version 1.0.16
    * Split schematic into focused sheets
    * Publish tscircuit package 1.0.19
    * Give schematic sheets meaningful names
